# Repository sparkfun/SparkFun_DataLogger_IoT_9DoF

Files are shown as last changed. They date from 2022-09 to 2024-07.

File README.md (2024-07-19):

SparkFun DataLogger IoT – 9DoF
========================================

SparkFun DataLogger IoT – 9DoF (https://www.sparkfun.com/products/20594)

[*SparkFun DataLogger IoT – 9DoF (DEV-20594)*](https://www.sparkfun.com/products/20594)

An IoT-enabled ESP32-based logger with on-board IMU and magnetometer. The microSD interface is full 4-bit SDIO for fast logging.

Repository Contents
-------------------
* **/Firmware** - Example code for hardware testing
* **/Hardware** - Eagle design files (.brd, .sch)

Documentation
-------------------

* **[Hookup Guide](https://docs.sparkfun.com/SparkFun_DataLogger/)** - Basic hookup guide for the Datalogger IoT
* **[Firmware](https://github.com/sparkfun/SparkFun_DataLogger/)** - Repo for the Datalogger IoT

Product Versions
----------------

* [DEV-20594](https://www.sparkfun.com/products/20594) - v1.1 & v1.2 (minor silkscreen change)

Version History
---------------
- V1.2 - DataLogger IoT – 9DoF with minor silkscreen change
- V1.1 - Initial release, rename to DataLogger IoT – 9DoF

License Information
-------------------

This hardware and the hardware test sketches contained in this GitHub repo are _**open source**_!

Please review the LICENSE.md file for license information. 

If you have any questions or concerns on licensing, please contact technical support on our [SparkFun forums](https://forum.sparkfun.com/viewforum.php?f=152).

Distributed as-is; no warranty is given.

- Your friends at SparkFun.

_<COLLABORATION CREDIT>_

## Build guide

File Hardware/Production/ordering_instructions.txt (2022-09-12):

panel size, 116x155mm
PCB thickness, 1.6mm
number of layers, 4
soldermask color, Red
silkscreen color, White
oz copper, 1oz
finish, HASL lead free
stencils, top+bottom
pcs per panel, 6
min trace width, 0.1524mm / 0.0060in
min drill size, 0.3000mm / 0.0118in
filename to layer stackup 1/2/3/4: GTL, GL2, GL3, GBL

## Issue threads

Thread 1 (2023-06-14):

DATALOGGER IOT - 9DOF DOES NOT RECOGNIZE SAM-M8Q GPS BOARD

csqrd, 2023-06-14:
It appears that the datalogger does not recognize the M8Q as it does not show up as a device along with the other 3 built-in devices. I updated the datalogger to firmware version 01.00.02 which did not resolve the issue. I verified that the SAM-M8Q board is functioning properly by using the U-Blox u-center software and a SparkFun u-blox GNSS Arduino example sketch. The I2C address is 0x42. Any help would be appreciated.

 I did notice "[W] GNSS::isConnected no traffic seen (first attempt)" message but would expect the module to show up in the device list? I assumed a GPS fix was established by the 1 per second flashing "PPM" LED but will need to use a arduino sketch to confirm.

Here is the datalogger output:

ets Jul 29 2019 12:21:46

rst:0x1 (POWERON_RESET),boot:0x13 (SPI_FAST_FLASH_BOOT)
configsip: 0, SPIWP:0xee
clk_drv:0x00,q_drv:0x00,d_drv:0x00,cs0_drv:0x00,hd_drv:0x00,wp_drv:0x00
mode:DIO, clock div:1
load:0x3fff0030,len:1344
load:0x40078000,len:13924
ho 0 tail 12 room 4
load:0x40080400,len:3600
entry 0x400805f0
E (1096) sdmmc_common: sdmmc_init_ocr: send_op_cond (1) returned 0x107
E (1097) vfs_fat_sdmmc: sdmmc_card_init failed (0x107).
[E] Startup of the SD card failed.
[W] Error initializing the SD Card. Is an SD card installed on the board?

SparkFun DataLogger IoT - 9DOF (c) 2023 SparkFun Electronics
Version: 01.00.02 - build 000098

[W] GNSS::isConnected no traffic seen (first attempt)
Restoring System Settings ...restored from ESP32 Preferences
Connecting to WiFi...Connected to gnet
NTP startup [5 secs].......enabled
Loading devices ... 3 devices detected
MAX17048 - MAX17048 LiPo Battery Fuel Gauge {qwiic}
ISM330 - ISM330 Inertial Measurement Unit {SPI}
MMC5983 - MMC5983 Magnetometer {SPI}

Time: 2023-06-12T14:40:59
Uptime: 0 days, 00:00:16.246
External Time Source: NTP Client
Board Name: SparkFun DataLogger IoT - 9DoF
Board ID: SFD1D085B886E694
SD card not available
[I] WiFi - Connected SSID: gnet IP Address: 192.168.xxx.xxx Signal: Excellent
[I] Battery - Not Connected
[I] System Deep Sleep: disabled
Sleep Interval: 0 seconds
Wake Interval: 0 seconds

[I] Logging Interval (ms): 15000
[I] Serial Output: CSV Format
Baud Rate: 115200

PaulZC, 2023-06-17:
Hi @csqrd ,

Apologies for the inconvenience. I can replicate this issue.

TLDR: I think the root cause is a flaw in the DataLogger firmware driver for the u-blox GNSS. I think it is caused by the way the GNSS module is detected - by looking for messages coming from the module. This works the first time - when the module is outputting NMEA messages by default. But the driver then disables the NMEA messages, saves the port configuration, and only then enables the UBX-NAV-PVT message. When the DataLogger firmware restarts, there are no NMEA messages (because they have been disabled), and no PVT messages (because the PVT message configuration is not saved).

I will confirm this, talk to my colleagues and get this fixed in the next release.

Very best wishes,
Paul

csqrd, 2023-06-17:
Thanks for the explanation.  Excited for a fix as I have several projects planed.

PaulZC, 2023-06-20:
Hi @csqrd ,

Thank you for your patience. We have a working fix for this. A new version of the firmware will be available shortly.

Best wishes,
Paul

DragonFlameBoy, 2023-07-12:
Hello

This is my first post so apologies if this is not the correct posting approach.

I have the same issue with the **GPS-18037 MAX-M10S** its not recognised except for the fist line - just as with the SAM-M8Q so I assume its the same issue?

SparkFun DataLogger IoT - 9DOF   (c) 2023 SparkFun Electronics
Version: 01.00.02  - build 000098
[W] GNSS::isConnected no traffic seen (first attempt)
[I] Restoring System Settings ...restored from ESP32 Preferences
[I] Connecting to WiFi...Connected to Vulcan
[I] NTP startup [5 secs].......enabled
[I] Loading devices ... 3 devices detected
    MAX17048              - MAX17048 LiPo Battery Fuel Gauge  {qwiic}
    ISM330                - ISM330 Inertial Measurement Unit  {SPI}
    MMC5983               - MMC5983 Magnetometer  {SPI}

gigapod, 2023-07-12:
Hi -

This is fixed and will be in the next build/release.

If everything goes well, this should be wrapped on on Friday and published.

Thanks for your patience!

-Kirk

gigapod, 2023-07-14:
Firmware version 1.00.03 was just published and includes the fix for this issue.

The update can be applied via the menu system on the DataLogger - See update  instructions [here](https://docs.sparkfun.com/SparkFun_DataLogger/configuration/#advanced-system-update)

DragonFlameBoy, 2023-07-15:
I can confirm Firmware version 1.00.03 resolves the issue with GPS-18037 MAX-M10S.  I now get the following additional information logged on the SparkFun DataLogger IoT - 9DOF:

GNSS.Year
GNSS.Month
GNSS.Day
GNSS.Hour
GNSS.Minute
GNSS.Second
GNSS.Latitude (deg)
GNSS.Longitude (deg)
GNSS.Altitude (m)
GNSS.Altitude MSL (m)
GNSS.SIV
GNSS.Fix Type
GNSS.Carrier Solution
GNSS.Ground Speed (m/s)
GNSS.Heading (deg)
GNSS.PDOP
GNSS.Horizontal Accuracy Estima
GNSS.Vertical Accuracy Estimate
GNSS.TOW (ms)
GNSS.ISO8601
GNSS.YYYYMMDD
GNSS.YYYYDDMM
GNSS.DDMMYYYY
GNSS.HHMMSS
GNSS.Fix Type (String)
GNSS.Carrier Solution (String)

Many thanks to **csqrd** for reporting this and SparkFun for resolving this.

Chris

gigapod, 2023-07-17:
@DragonFlameBoy  - thank you for verifying the fix  is working - always helpful to get feedback.

If you have any other issues/inputs - don't hesitate to file an issue here, or on the repo we use for the firmware (https://github.com/sparkfun/SparkFun_DataLogger/tree/main).

-Kirk

csqrd, 2023-07-17:
I can verify that the M8Q works as well.
Thanks!

Closed 2023-07-14.

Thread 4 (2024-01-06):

DataLogger IoT upload format

JimKruk, 2024-01-06:
I bought this board https://www.sparkfun.com/products/20594 SparkFun DataLogger IoT with a SF TMP117 temp sensor plugged in the board. I am using the adafruit IO mqtt service. After configuring the parms for the mqtt service, wifi and the logging interval everything seems to start and connect ok:

SparkFun DataLogger IoT (c) 2023 SparkFun Electronics
Version: 01.00.04 - build 0000bb

Restoring System Settings ...restored from ESP32 Preferences
Connecting to WiFi...Connected to NETGEARMR1100
NTP startup [5 secs]...enabled
MQTT Client: connecting to MQTT endpoint io.adafruit.com:1883 ...connected
Loading devices ... 2 devices detected
TMP117 - TMP117 Precision Temperature Sensor {qwiic}
MAX17048 - MAX17048 LiPo Battery Fuel Gauge {qwiic}

Time: 2024-01-01T10:59:47
Uptime: 0 days, 00:00:09.756
External Time Source: NTP Client
Board Name: SparkFun DataLogger IoT
Board ID: SFD248966B65B7A0
[I] SD card not available
[I] WiFi - Connected SSID: NETGEARMR1100 IP Address: 192.168.1.83 Signal: Fair
[I] Battery - Not Connected
[I] System Deep Sleep: disabled
Sleep Interval: 60 seconds
Wake Interval: 120 seconds
[I] Logging Interval (ms): 60000
[I] Serial Output: Disabled
Baud Rate: 115200
[I] SD Card Output: Disabled
Rotate Period: 24 Hours

[I] IoT Services:
MQTT Client : enabled
MQTT Secure Client : disabled
HTTP IoT : disabled
AWS IoT : disabled
Azure IoT : disabled
ThingSpeak MQTT : disabled
MachineChat : disabled

[I] Connected Devices [2]:
TMP117 - TMP117 Precision Temperature Sensor {qwiic}
MAX17048 - MAX17048 LiPo Battery Fuel Gauge {qwiic}

I called the mqtt topic:
Settings for: /SparkFun DataLogger IoT/Settings/MQTT Client/MQTT Topic
Edit the value of `MQTT Topic` - data type <string>
When complete, press <Return> to accept, <ESC> to discard
MQTT Topic = zzzzzzzz/feeds/datalogger.tmp117

I disabled the outputs for the 3 fields of the max17048 device in /SparkFun DataLogger IoT/Devices Settings/MAX17048

Settings for: /SparkFun DataLogger IoT/Devices Settings/MAX17048
Outputs:
1) Voltage (V) - Battery voltage (Volts)
2) State Of Charge (%) - Battery state of charge (%)
3) Change Rate (%/hr) - Battery charge change rate (%/hr)

When I open the web console of adafruit IO I am seeing updates once a minute but in the 'value' of the tmp117 feed I see this as the value:

{"TMP117":{"Temperature (C)":27.96875},"MAX17048":{}}

I just want to see the data value for "Temperature (C)" of 27.96875 not the entire string above

Is there a config setting for that somewhere ?
thanks

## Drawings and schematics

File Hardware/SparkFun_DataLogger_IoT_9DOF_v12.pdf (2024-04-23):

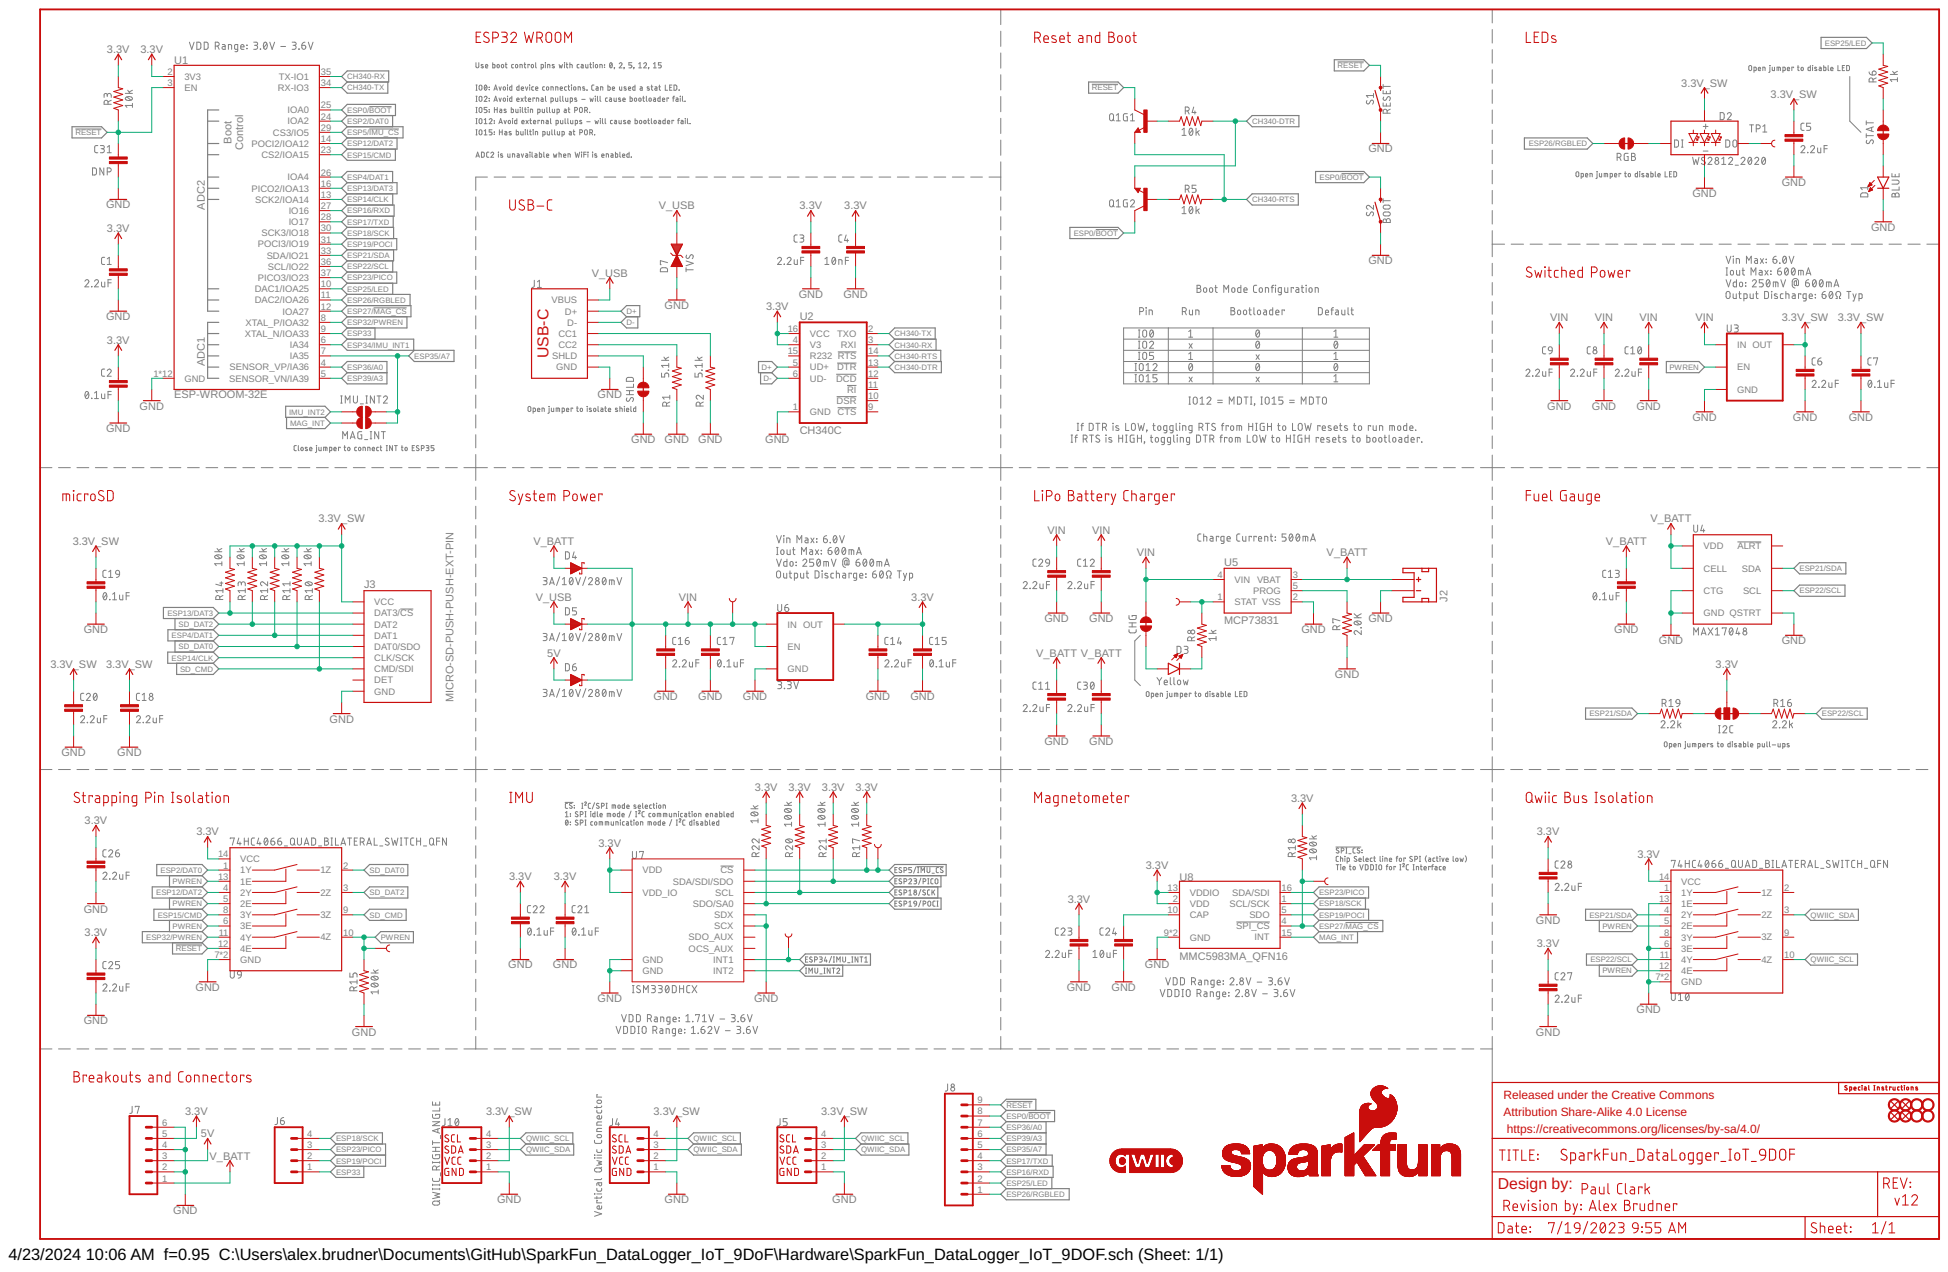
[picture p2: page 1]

GND QSTRT SCL SDA

VCC
DAT3/CS CMD/SDI DAT0/SDO
DAT2 DAT1 CLK/SCK DET

Released under the Creative Commons Attribution Share-Alike 4.0 License

https://creativecommons.org/licenses/by-sa/4.0/

4/23/2024 10:06 AM f=0.95 C:\Users\alex.brudner\Documents\GitHub\SparkFun_DataLogger_IoT_9DoF\Hardware\SparkFun_DataLogger_IoT_9DOF.sch (Sheet: 1/1)

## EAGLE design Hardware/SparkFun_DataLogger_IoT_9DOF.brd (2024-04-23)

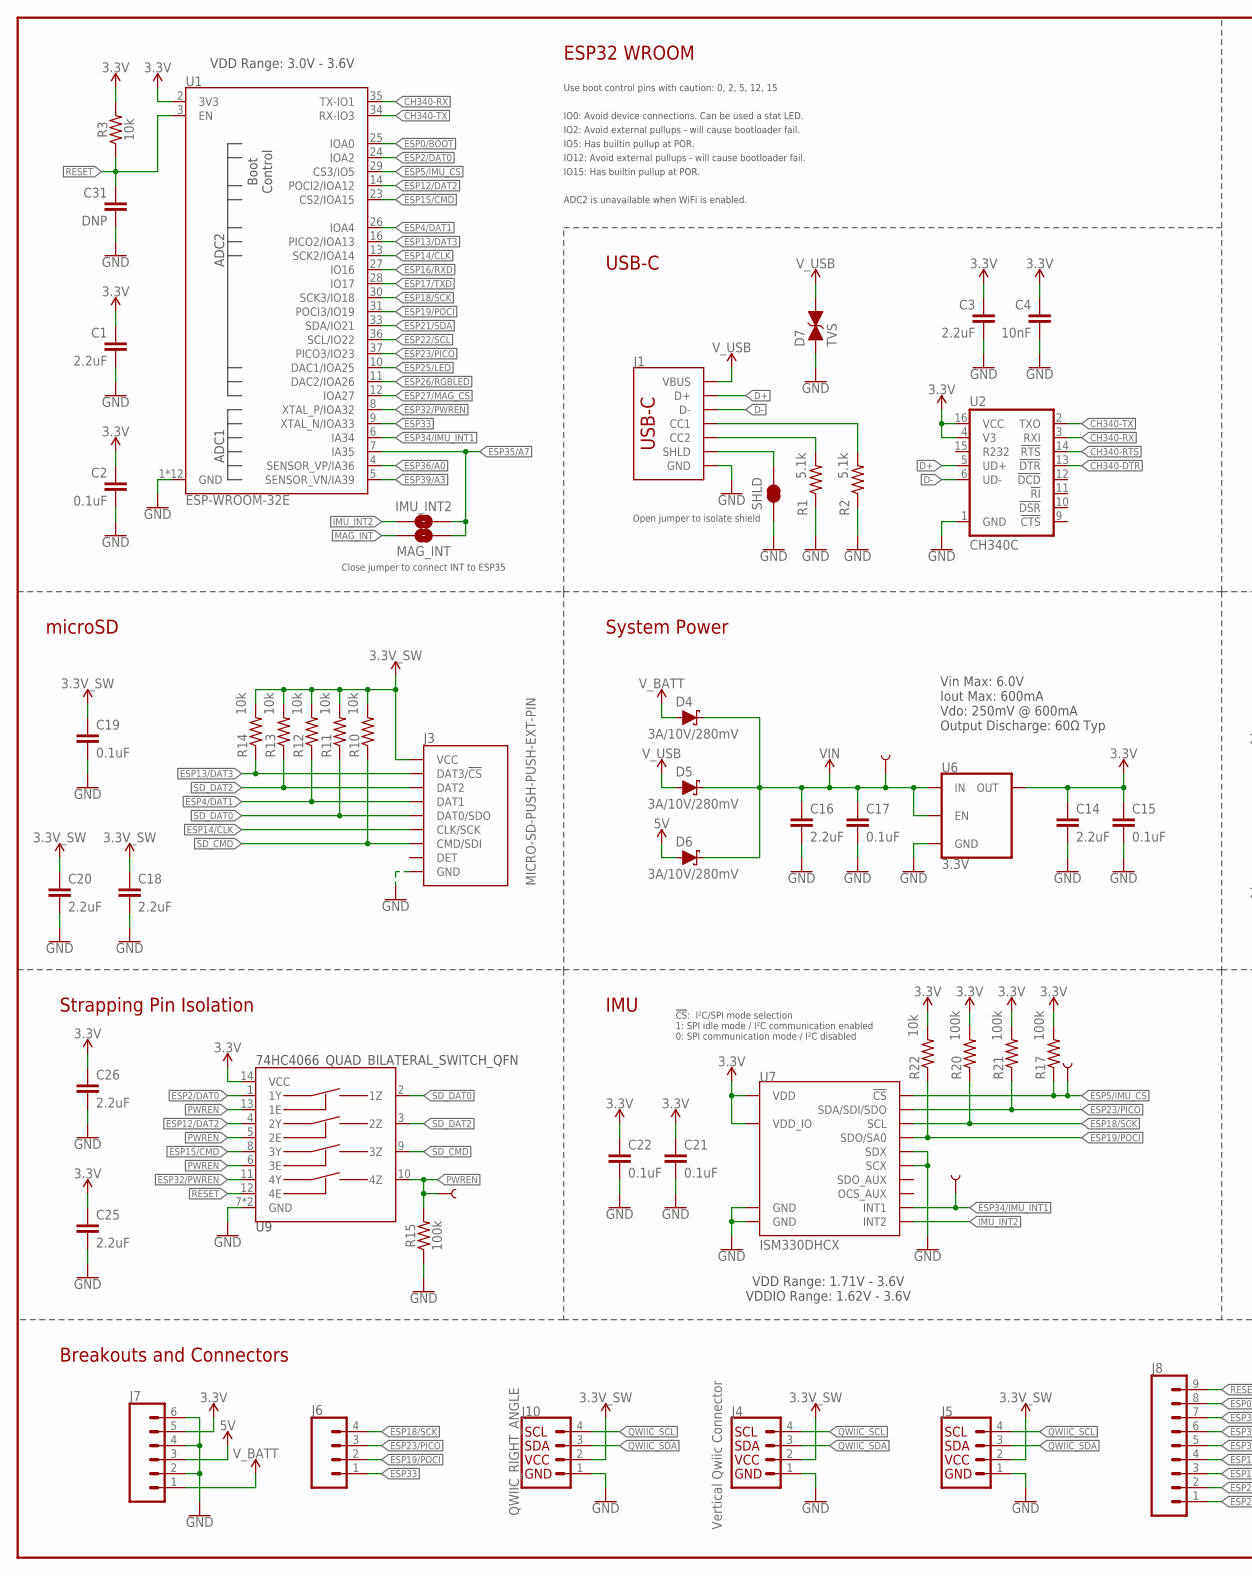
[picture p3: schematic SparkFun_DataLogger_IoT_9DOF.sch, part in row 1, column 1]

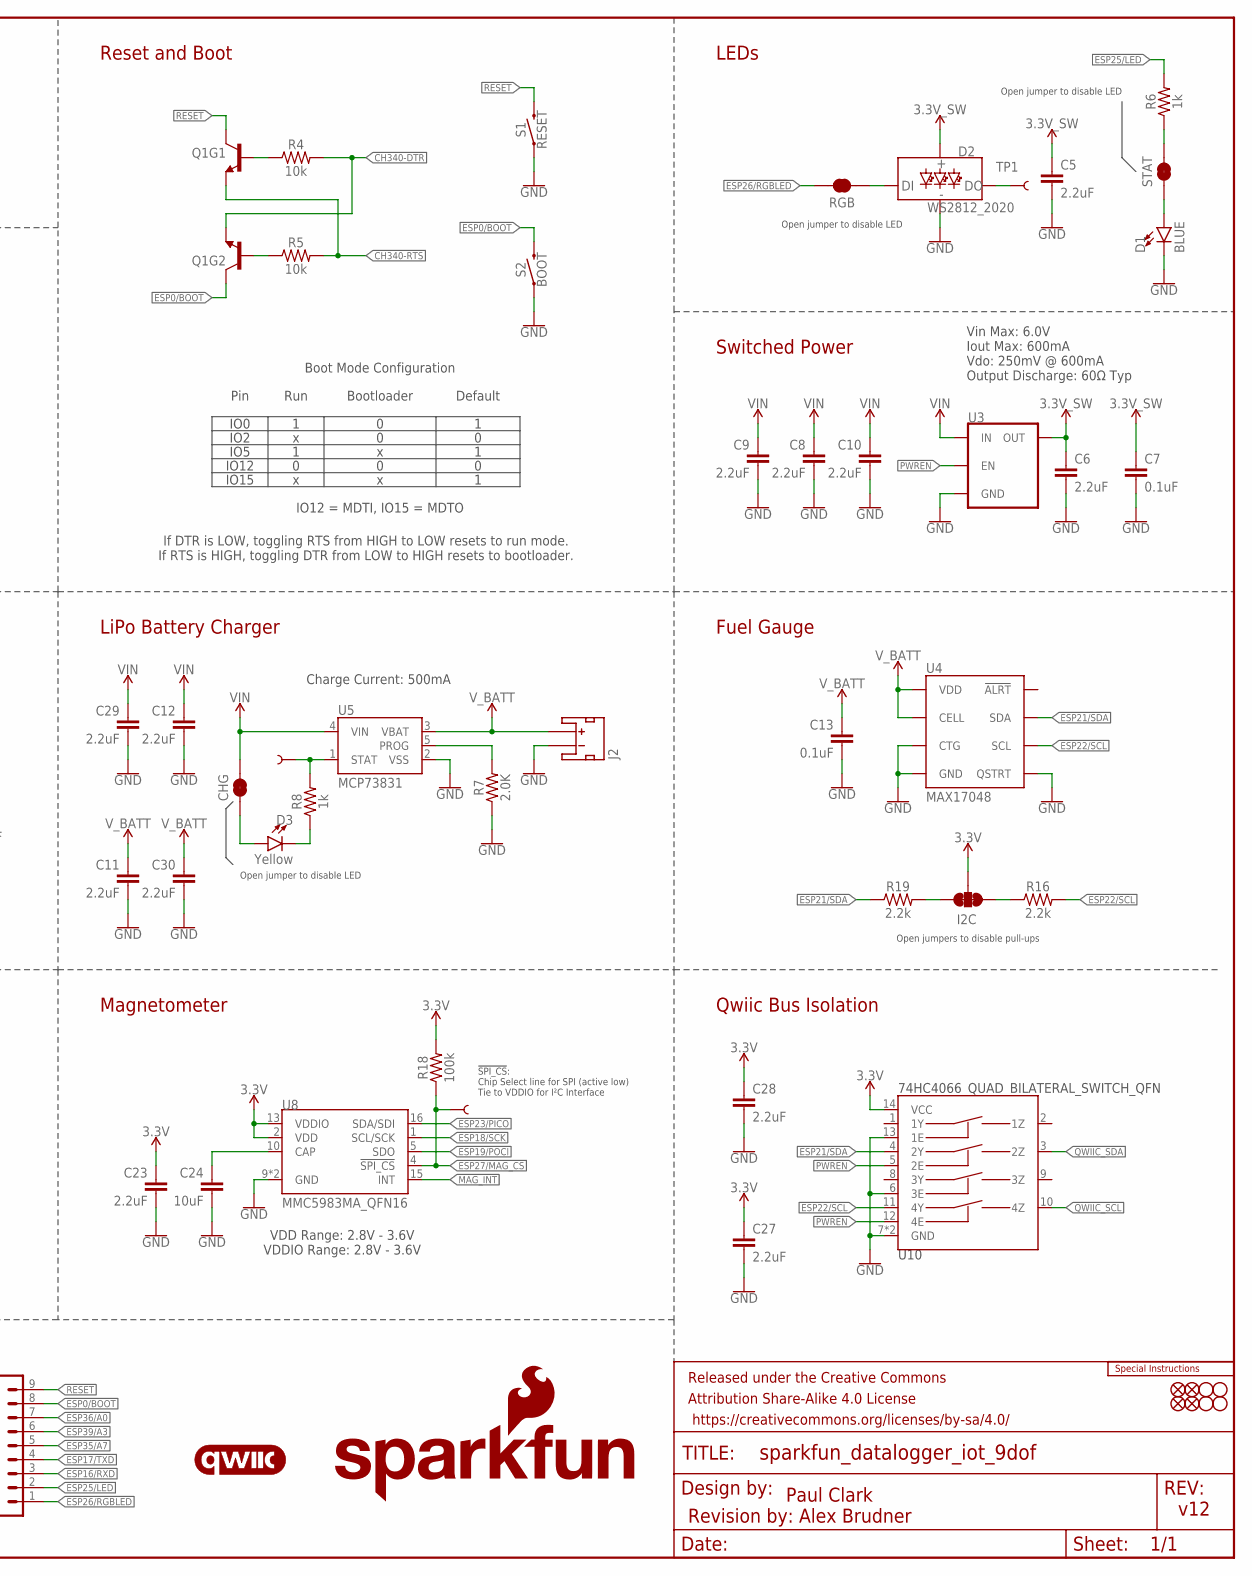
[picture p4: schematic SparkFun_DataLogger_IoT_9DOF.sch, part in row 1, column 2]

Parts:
C1, C3, C5, C6, C8, C9, C10, C11, C12, C14, C16, C18, C20, C23, C25, C26, C27, C28, C29, C30: 2.2uF; 0402-TIGHT
C2, C7, C13, C15, C17, C19, C21, C22: 0.1uF; 0402-TIGHT
C4: 10nF; 0402-TIGHT
C24: 10uF; 0402-TIGHT
C31: DNP; 0402-TIGHT_NO_CREAM
CHG: JUMPER-SMT_2_NC_TRACE_SILK; SMT-JUMPER_2_NC_TRACE_SILK
D1: BLUE; LED-0603
D2: WS2812_2020; WS2812-2020
D3: Yellow; LED-0603
D4, D5, D6: 3A/10V/280mV; SOD-323
D7: TVS; 0603
FD1, FD2, FD3, FD4: FIDUCIAL1X2; FIDUCIAL-1X2
FRAME1: FRAME-LEDGER; CREATIVE_COMMONS
H1, H2, H3, H4: STAND-OFFTIGHT; STAND-OFF-TIGHT
I2C: JUMPER-SMT_3_2-NC_TRACE_SILK; SMT-JUMPER_3_2-NC_TRACE_SILK
IMU_!CS!: TEST-POINT3X5; PAD.03X.05
IMU_INT1: TEST-POINT3X5; PAD.03X.05
IMU_INT2: JUMPER-SMT_2_NO_SILK; SMT-JUMPER_2_NO_SILK
J1: USB_C_4-LAYER_PADS; USB-C-16P_4LAYER-PADS
J2: JST_2MM_MALE; JST-2-SMD
J3: MICRO-SD-PUSH-PUSH-EXT-PIN; MICROSD-EXTERNALPIN
J4: Vertical Qwiic Connector; JST04_1MM_VERT
J5: I2C_STANDARD_NO_SILK; 1X04_NO_SILK
J6: CONN_041X04_NO_SILK_NO_POP; 1X04_NO_SILK
J7: CONN_06NO_SILK_NO_POP; 1X06_NO_SILK
J8: CONN_09NO_SILK; 1X09_NO_SILK
J10: QWIIC_RIGHT_ANGLE; JST04_1MM_RA
LOGO1: SPECIAL_INSTRUCTIONS-ORDERING; ORDERING_INSTRUCTIONS
LOGO3: QWIIC_LOGO_6MM; QWIIC_6MM
LOGO5: SFE_LOGO_NAME.2_INCH; SFE_LOGO_NAME_.2
LOGO6: SFE_LOGO_FLAME.2_INCH; SFE_LOGO_FLAME_.2
MAG_!CS!: TEST-POINT3X5; PAD.03X.05
MAG_INT: JUMPER-SMT_2_NO_SILK; SMT-JUMPER_2_NO_SILK
PWREN: TEST-POINT3X5; PAD.03X.05
Q1: TRANS_NPN_DUAL-MBT3904DW1T1; SC70-6
R1, R2: 5.1k; 0402-TIGHT
R3, R4, R5, R10, R11, R12, R13, R14, R22: 10k; 0402-TIGHT
R6, R8: 1k; 0402-TIGHT
R7: 2.0K; 0402-TIGHT
R15, R17, R18, R20, R21: 100k; 0402-TIGHT
R16, R19: 2.2k; 0402-TIGHT
RGB: JUMPER-SMT_2_NC_TRACE_SILK; SMT-JUMPER_2_NC_TRACE_SILK
S1: RESET; TACTILE_SWITCH_SMD_RIGHT_ANGLE
S2: BOOT; TACTILE_SWITCH_SMD_RIGHT_ANGLE
SHLD: JUMPER-SMT_2_NC_TRACE_SILK; SMT-JUMPER_2_NC_TRACE_SILK
STAT: JUMPER-SMT_2_NC_TRACE_SILK; SMT-JUMPER_2_NC_TRACE_SILK
TP1: TEST-POINT3X5; PAD.03X.05
U1: ESP-WROOM-32E; ESP-WROOM-32D-NARROW
U2: CH340C; SO016
U3, U6: 3.3V; SOT23-5
U4: MAX17048; DFN-8
U5: MCP73831; SOT23-5
U7: ISM330DHCX; LGA-14L
U8: MMC5983MA_QFN16; LGA-16-3X3MM-4X4PINS
U9, U10: 74HC4066_QUAD_BILATERAL_SWITCH_QFN; 14-QFN
VIN, VIN1: TEST-POINT3X5; PAD.03X.05

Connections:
3.3V: C1.1, C2.1, C3.1, C4.1, C14.1, C15.1, C21.1, C22.1, C23.1, C25.1, C26.1, C27.1, C28.1, I2C.2, J7.5, R3.2, R17.2, R18.2, R20.2, R21.2, R22.2, U1.2 (3V3), U2.4 (V3), U2.16 (VCC), U6.5 (OUT), U7.P5 (VDD_IO), U7.P8 (VDD), U8.2 (VDD), U8.13 (VDDIO), U9.14 (VCC), U10.14 (VCC)
3.3V_SW: C5.1, C6.1, C7.1, C18.1, C19.1, C20.1, D2.VCC, J3.4 (VCC), J4.2, J5.2, J10.2, R10.2, R11.2, R12.2, R13.2, R14.2, U3.5 (OUT)
5V: D6.A, J7.3
!RESET!: C31.1, J8.9, Q1.3 (C), R3.1, S1.2, U1.3 (EN), U9.12 (4E)
CAP: C24.1, U8.10 (CAP)
CH340-DTR: Q1.1 (E), R4.2, U2.13 (!DTR)
CH340-RTS: Q1.4 (E), R5.2, U2.14 (!RTS)
CH340-RX: U1.35 (TX-IO1), U2.3 (RXI)
CH340-TX: U1.34 (RX-IO3), U2.2 (TXO)
D+: J1.A6 (D+), J1.B6 (D+), U2.5 (UD+)
D-: J1.A7 (D-), J1.B7 (D-), U2.6 (UD-)
ESP0/!BOOT!: J8.8, Q1.6 (C), S2.2, U1.25 (IOA0)
ESP2/DAT0: U1.24 (IOA2), U9.1 (1Y)
ESP4/DAT1: J3.8 (DAT1), R12.1, U1.26 (IOA4)
ESP5/!IMU_CS!: IMU_!CS!.1, R17.1, U1.29 (CS3/IO5), U7.P12 (!CS!)
ESP12/DAT2: U1.14 (POCI2/IOA12), U9.4 (2Y)
ESP13/DAT3: J3.2 (DAT3/!CS!), R14.1, U1.16 (PICO2/IOA13)
ESP14/CLK: J3.5 (CLK/SCK), U1.13 (SCK2/IOA14)
ESP15/CMD: U1.23 (CS2/IOA15), U9.8 (3Y)
ESP16/RXD: J8.3, U1.27 (IO16)
ESP17/TXD: J8.4, U1.28 (IO17)
ESP18/SCK: J6.4, R20.1, U1.30 (SCK3/IO18), U7.P13 (SCL), U8.1 (SCL/SCK)
ESP19/POCI: J6.2, R22.1, U1.31 (POCI3/IO19), U7.P1 (SDO/SA0), U8.5 (SDO)
ESP21/SDA: R19.1, U1.33 (SDA/IO21), U4.8 (SDA), U10.4 (2Y)
ESP22/SCL: R16.2, U1.36 (SCL/IO22), U4.7 (SCL), U10.11 (4Y)
ESP23/PICO: J6.3, R21.1, U1.37 (PICO3/IO23), U7.P14 (SDA/SDI/SDO), U8.16 (SDA/SDI)
ESP25/LED: J8.2, R6.2, U1.10 (DAC1/IOA25)
ESP26/RGBLED: J8.1, RGB.2, U1.11 (DAC2/IOA26)
ESP27/!MAG_CS!: MAG_!CS!.1, R18.1, U1.12 (IOA27), U8.4 (!SPI_CS!)
ESP32/PWREN: U1.8 (XTAL_P/IOA32), U9.11 (4Y)
ESP33: J6.1, U1.9 (XTAL_N/IOA33)
ESP34/IMU_INT1: IMU_INT1.1, U1.6 (IA34), U7.P4 (INT1)
ESP35/A7: IMU_INT2.2, J8.5, MAG_INT.2, U1.7 (IA35)
ESP36/A0: J8.7, U1.4 (SENSOR_VP/IA36)
ESP39/A3: J8.6, U1.5 (SENSOR_VN/IA39)
GND: C1.2, C2.2, C3.2, C4.2, C5.2, C6.2, C7.2, C8.2, C9.2, C10.2, C11.2, C12.2, C13.2, C14.2, C15.2, C16.2, C17.2, C18.2, C19.2, C20.2, C21.2, C22.2, C23.2, C24.2, C25.2, C26.2, C27.2, C28.2, C29.2, C30.2, C31.2, D1.C, D2.GND, D7.1 (A), J1.GND, J1.GND2 (GND), J2.1 (-), J3.6 (GND), J3.10 (GND), J3.11 (GND), J3.12 (GND), J3.13 (GND), J4.1, J5.1, J7.2, J7.4, J7.6, J10.1, R1.1, R2.1, R7.1, R15.1, S1.1, S2.1, SHLD.1, U1.1 (GND), U1.15 (GND), U1.38 (GND), U1.GND1 (GND), U1.GNDT1 (GND), U1.GNDT2 (GND), U1.GNDT3 (GND), U1.GNDT4 (GND), U1.GNDT5 (GND), U1.GNDT6 (GND), U1.GNDT7 (GND), U1.GNDT8 (GND), U2.1 (GND), U3.2 (GND), U4.1 (CTG), U4.4 (GND), U4.6 (QSTRT), U4.9 (GND), U5.2 (VSS), U6.2 (GND), U7.P2 (SDX), U7.P3 (SCX), U7.P6 (GND), U7.P7 (GND), U8.9 (GND), U8.11 (GND), U9.7 (GND), U9.EPAD (GND), U10.6 (3E), U10.7 (GND), U10.13 (1E), U10.EPAD (GND)
IMU_INT2: IMU_INT2.1, U7.P9 (INT2)
MAG_INT: MAG_INT.1, U8.15 (INT)
unnamed: J1.B5 (CC2), R1.2
unnamed: J1.A5 (CC1), R2.2
unnamed: Q1.2 (B), R5.1
unnamed: Q1.5 (B), R4.1
unnamed: R6.1, STAT.2
unnamed: D2.DO, TP1.1
unnamed: CHG.1, D3.A
unnamed: D3.C, R8.1
unnamed: R8.2, U5.1 (STAT), VIN1.1
unnamed: R7.2, U5.5 (PROG)
unnamed: D2.DI, RGB.1
unnamed: D1.A, STAT.1
unnamed: I2C.1, R16.1
unnamed: I2C.3, R19.2
PWREN: PWREN.1, R15.2, U3.3 (EN), U9.5 (2E), U9.6 (3E), U9.10 (4Z), U9.13 (1E), U10.5 (2E), U10.12 (4E)
QWIIC_SCL: J4.4, J5.4, J10.4, U10.10 (4Z)
QWIIC_SDA: J4.3, J5.3, J10.3, U10.3 (2Z)
SD_CMD: J3.3 (CMD/SDI), R10.1, U9.9 (3Z)
SD_DAT0: J3.7 (DAT0/SDO), R11.1, U9.2 (1Z)
SD_DAT2: J3.1 (DAT2), R13.1, U9.3 (2Z)
SHIELD: J1.SHLD1 (SHLD), J1.SHLD2 (SHLD), J1.SHLD3 (SHLD), J1.SHLD4 (SHLD), SHLD.2
VIN: C8.1, C9.1, C10.1, C12.1, C16.1, C17.1, C29.1, CHG.2, D4.C, D5.C, D6.C, U3.1 (IN), U5.4 (VIN), U6.1 (IN), U6.3 (EN), VIN.1
V_BATT: C11.1, C13.1, C30.1, D4.A, J2.2 (+), J7.1, U4.2 (CELL), U4.3 (VDD), U5.3 (VBAT)
V_USB: D5.A, D7.2 (C), J1.VBUS1 (VBUS), J1.VBUS2 (VBUS)

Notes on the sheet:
ESP32 WROOM
USB-C
Paul Clark
v12
Reset and Boot
LEDs
Switched Power
Fuel Gauge
LiPo Battery Charger
System Power
microSD
Strapping Pin Isolation
IMU
VDD Range: 1.71V - 3.6V VDDIO Range: 1.62V - 3.6V
VDD Range: 2.8V - 3.6V VDDIO Range: 2.8V - 3.6V
Magnetometer
Qwiic Bus Isolation
Breakouts and Connectors
Charge Current: 500mA
VDD Range: 3.0V - 3.6V
Vin Max: 6.0V Iout Max: 600mA Vdo: 250mV @ 600mA Output Discharge: 60Ω Typ
If DTR is LOW, toggling RTS from HIGH to LOW resets to run mode. If RTS is HIGH, toggling DTR from LOW to HIGH resets to bootloader.
Pin
IO0
IO2
IO12
IO15
IO5
Run
Bootloader
Default
IO12 = MDTI, IO15 = MDTO
Boot Mode Configuration
IO0: Avoid device connections. Can be used a stat LED.
ADC2 is unavailable when WiFi is enabled.
IO12: Avoid external pullups - will cause bootloader fail.
Use boot control pins with caution: 0, 2, 5, 12, 15
IO2: Avoid external pullups - will cause bootloader fail.
IO15: Has builtin pullup at POR.
IO5: Has builtin pullup at POR.

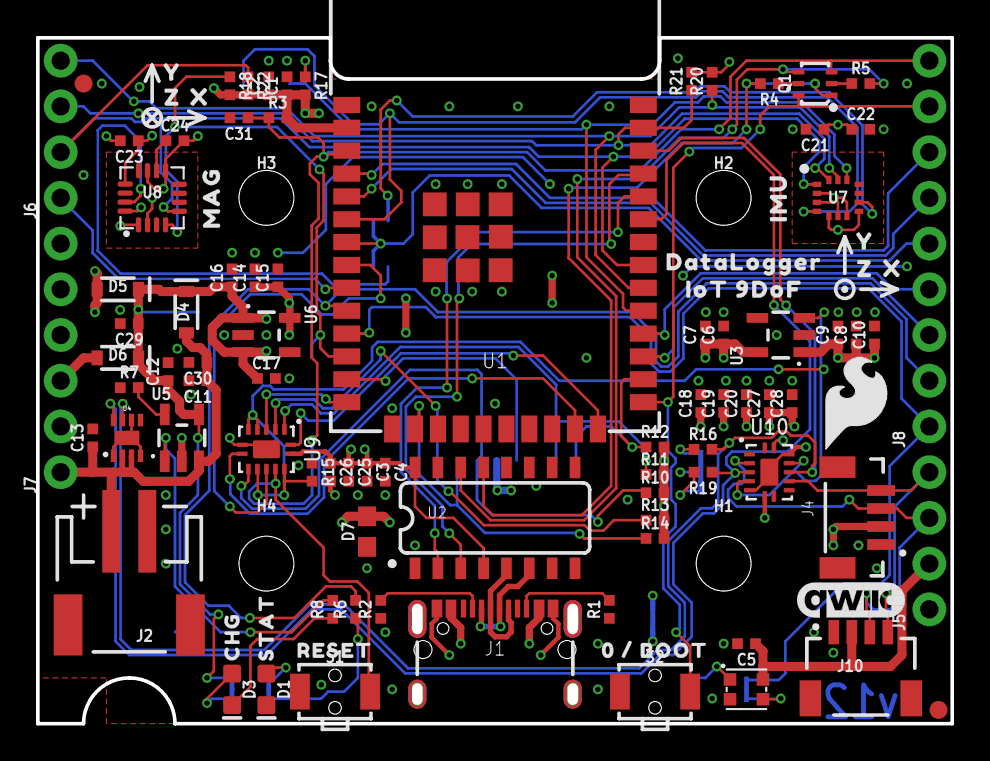
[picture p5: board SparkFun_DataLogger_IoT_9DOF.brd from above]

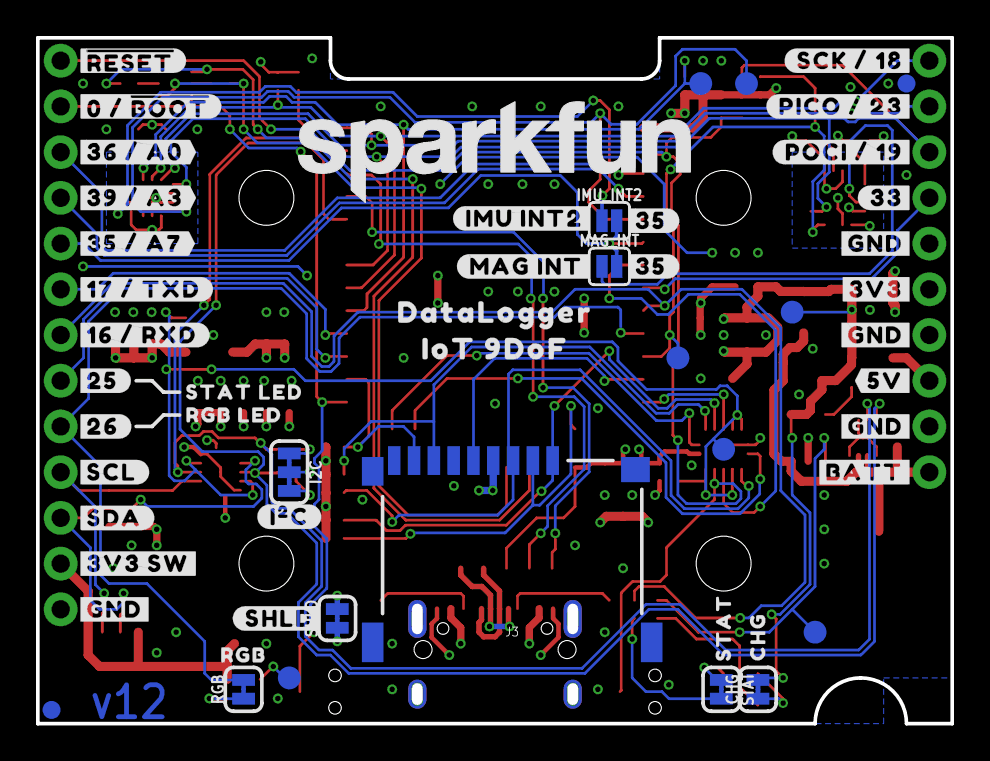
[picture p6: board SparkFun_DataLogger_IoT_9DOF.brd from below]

Board: 4 copper layers, 50.8 x 38.1 mm, 158 parts (54 on the bottom side), 62 nets.

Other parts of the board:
U$1: IOT_9DOF0
U$2: RESET0
U$3, U$6: STAT0
U$4, U$5: CHG0
U$7: 0_#_BOOT0
U$8: IMU0
U$9: MAG0
U$10, U$13: X0
U$11, U$14: Y0
U$12, U$15: Z0
U$16: ##RESET##0
U$17: #0_#_#BOOT##0
U$18: #36_#_A0#0
U$19: #39_#_A3#0
U$20: #35_#_A7#0
U$21: #17_#_TXD#0
U$22: #16_#_RXD#0
U$23: #25#0
U$24: #26#0
U$25: #SCL#0
U$26: #SDA#0
U$27: #3V3_SW#0
U$28: #GND#0
U$29, U$30, U$31: #GND#1
U$32: #BATT#0
U$33: #5V#0
U$34: #3V3#0
U$35: #33#0
U$36: #POCI_#_19#0
U$37: #PICO_#_23#0
U$38: #SCK_#_18#0
U$40: #IMU_INT2#0
U$41: #MAG_INT#0
U$42, U$43: #35#0
U$44: IOT_9DOF10
U$45: #SHLD#0
U$46: #I�C#0
U$47: STAT_LED0
U$48: RGB_LED0
U$49: RGB0
U$50: DATALOGGER0
U$51: DATALOGGER1

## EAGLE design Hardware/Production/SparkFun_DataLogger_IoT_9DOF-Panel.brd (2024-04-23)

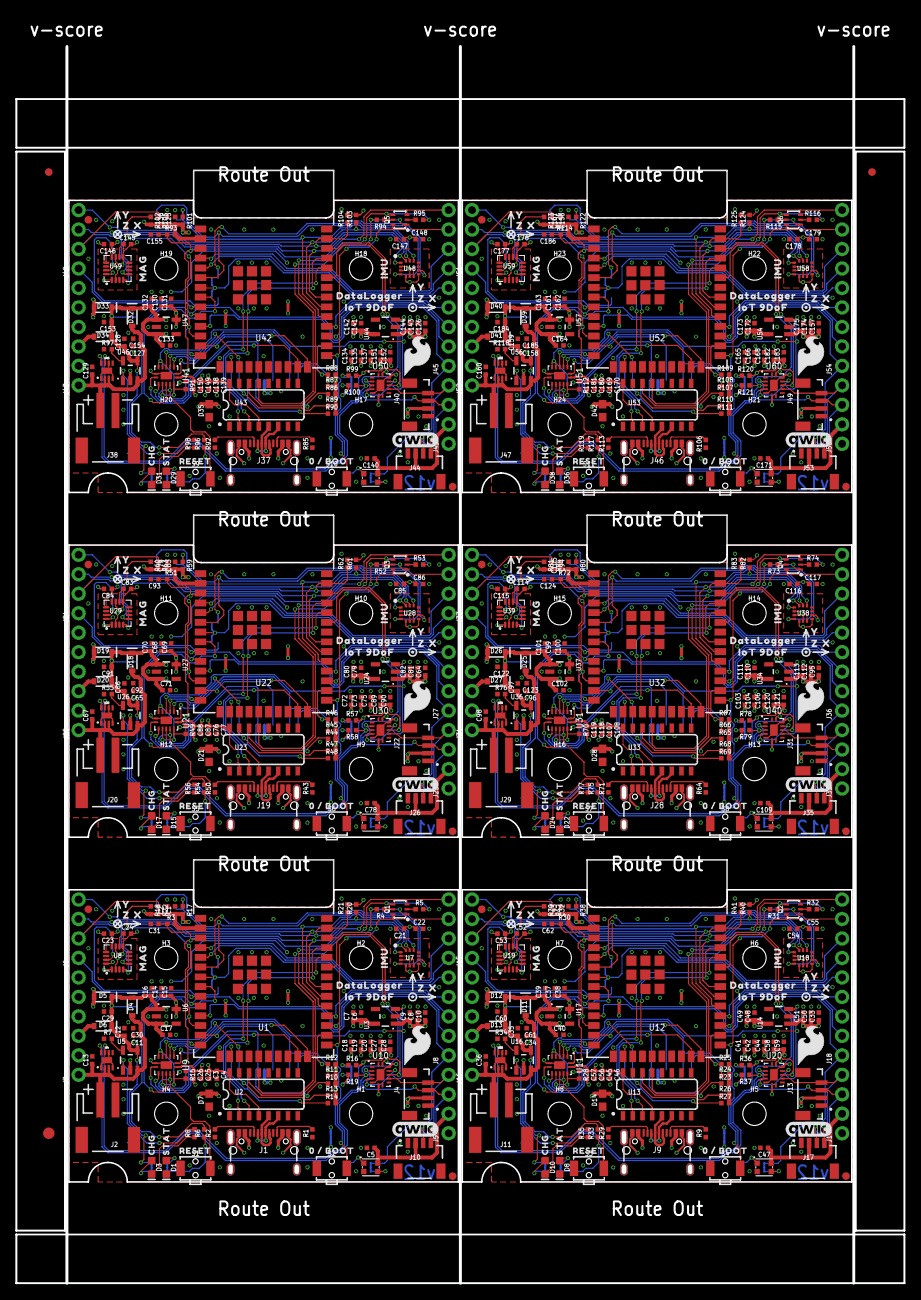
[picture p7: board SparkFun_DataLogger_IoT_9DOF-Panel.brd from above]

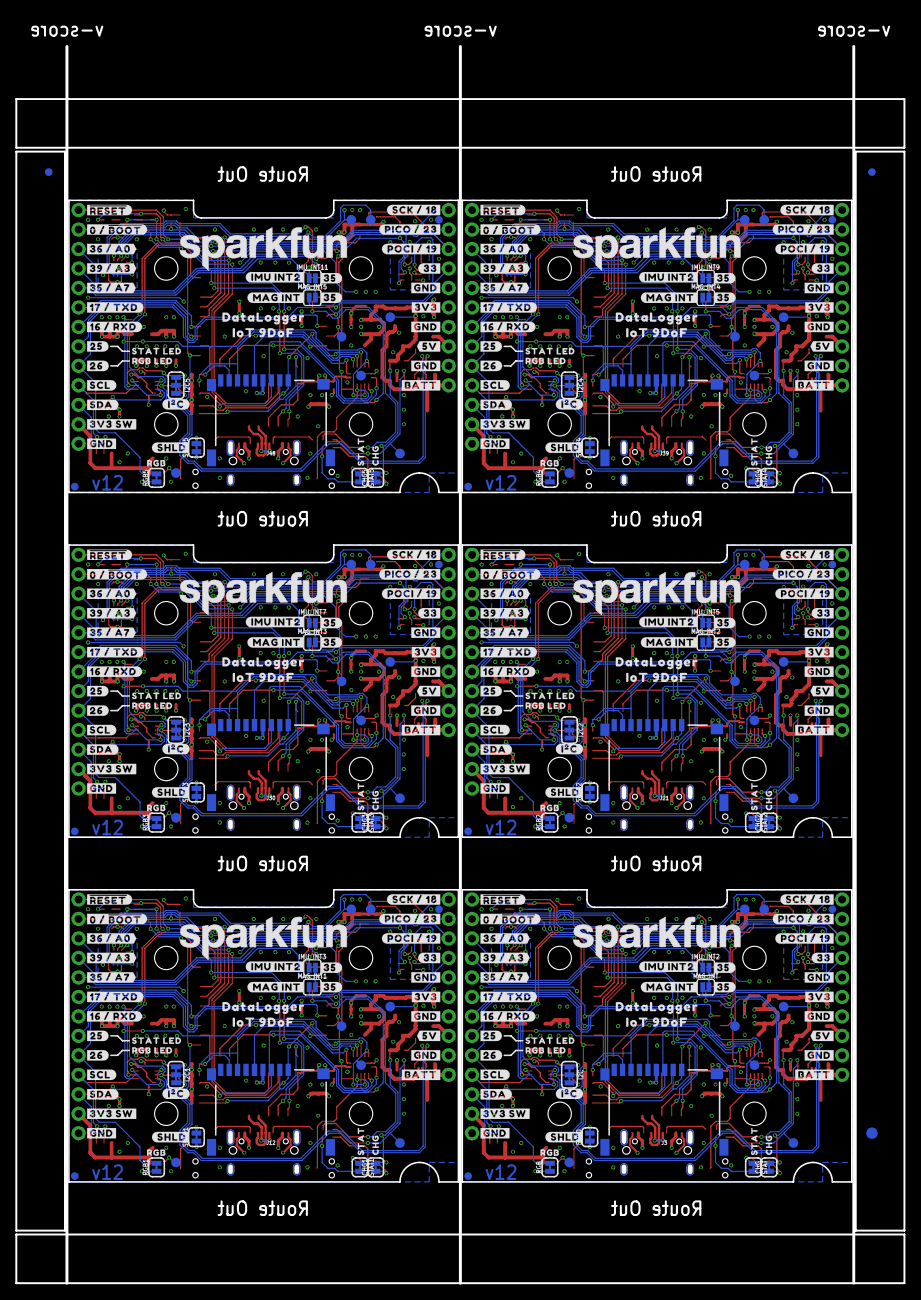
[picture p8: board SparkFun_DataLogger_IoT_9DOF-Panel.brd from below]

Board: 4 copper layers, 115.8 x 161.3 mm, 942 parts (327 on the bottom side), 372 nets.

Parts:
C1, C3, C5, C6, C8, C9, C10, C11, C12, C14, C16, C18, C20, C23, C25, C26, C27, C28, C29, C30, C32, C33, C34, C35, C37, C39, C41, C44, C45, C47, C48, C50, C51, C53, C56, C57, C58, C59, C60, C61, C63, C64, C65, C66, C68, C70, C72, C75, C76, C78, C79, C81, C82, C84, C87, C88, C89, C90, C91, C92, C94, C95, C96, C97, C99, C101, C103, C106, C107, C109, C110, C112, C113, C115, C118, C119, C120, C121, C122, C123, C125, C126, C127, C128, C130, C132, C134, C137, C138, C140, C141, C143, C144, C146, C149, C150, C151, C152, C153, C154, C156, C157, C158, C159, C161, C163, C165, C168, C169, C171, C172, C174, C175, C177, C180, C181, C182, C183, C184, C185: 2.2uF; 0402-TIGHT
C2, C7, C13, C15, C17, C19, C21, C22, C36, C38, C40, C42, C43, C49, C54, C55, C67, C69, C71, C73, C74, C80, C85, C86, C98, C100, C102, C104, C105, C111, C116, C117, C129, C131, C133, C135, C136, C142, C147, C148, C160, C162, C164, C166, C167, C173, C178, C179: 0.1uF; 0402-TIGHT
C4, C46, C77, C108, C139, C170: 10nF; 0402-TIGHT
C24, C52, C83, C114, C145, C176: 10uF; 0402-TIGHT
C31, C62, C93, C124, C155, C186: DNP; 0402-TIGHT_NO_CREAM
CHG, CHG1, CHG2, CHG3, CHG4, CHG5: JUMPER-SMT_2_NC_TRACE_SILK; SMT-JUMPER_2_NC_TRACE_SILK
D1, D8, D15, D22, D29, D36: BLUE; LED-0603
D2, D9, D16, D23, D30, D37: WS2812_2020; WS2812-2020
D3, D10, D17, D24, D31, D38: Yellow; LED-0603
D4, D5, D6, D11, D12, D13, D18, D19, D20, D25, D26, D27, D32, D33, D34, D39, D40, D41: 3A/10V/280mV; SOD-323
D7, D14, D21, D28, D35, D42: TVS; 0603
E$1, E$2, E$3, E$4: FIDUCIAL-1X2
E$5, E$6: FIDUCIAL-1.5X3
FD1, FD2, FD3, FD4, FD5, FD6, FD7, FD8, FD9, FD10, FD11, FD12, FD13, FD14, FD15, FD16, FD17, FD18, FD19, FD20, FD21, FD22, FD23, FD24: FIDUCIAL1X2; FIDUCIAL-1X2
H1, H2, H3, H4, H5, H6, H7, H8, H9, H10, H11, H12, H13, H14, H15, H16, H17, H18, H19, H20, H21, H22, H23, H24: STAND-OFFTIGHT; STAND-OFF-TIGHT
I2C, I2C1, I2C2, I2C3, I2C4, I2C5: JUMPER-SMT_3_2-NC_TRACE_SILK; SMT-JUMPER_3_2-NC_TRACE_SILK
IMU_!CS!, IMU_!CS!1, IMU_!CS!2, IMU_!CS!3, IMU_!CS!4, IMU_!CS!5: TEST-POINT3X5; PAD.03X.05
IMU_INT1, IMU_INT4, IMU_INT6, IMU_INT8, IMU_INT10, IMU_INT12: TEST-POINT3X5; PAD.03X.05
IMU_INT2, IMU_INT3, IMU_INT5, IMU_INT7, IMU_INT9, IMU_INT11: JUMPER-SMT_2_NO_SILK; SMT-JUMPER_2_NO_SILK
J1, J9, J19, J28, J37, J46: USB-C-16P_4LAYER-PADS
J2, J11, J20, J29, J38, J47: JST-2-SMD
J3, J12, J21, J30, J39, J48: MICRO-SD-PUSH-PUSH-EXT-PIN; MICROSD-EXTERNALPIN
J4, J13, J22, J31, J40, J49: Vertical Qwiic Connector; JST04_1MM_VERT
J5, J6, J14, J15, J23, J24, J32, J33, J41, J42, J50, J51: 1X04_NO_SILK
J7, J16, J25, J34, J43, J52: 1X06_NO_SILK
J8, J18, J27, J36, J45, J54: 1X09_NO_SILK
J10, J17, J26, J35, J44, J53: QWIIC_RIGHT_ANGLE; JST04_1MM_RA
LOGO1, LOGO3, LOGO7, LOGO10, LOGO13, LOGO16: QWIIC_LOGO_6MM; QWIIC_6MM
LOGO2, LOGO5, LOGO8, LOGO11, LOGO14, LOGO17: SFE_LOGO_NAME.2_INCH; SFE_LOGO_NAME_.2
LOGO4, LOGO6, LOGO9, LOGO12, LOGO15, LOGO18: SFE_LOGO_FLAME.2_INCH; SFE_LOGO_FLAME_.2
MAG_!CS!, MAG_!CS!1, MAG_!CS!2, MAG_!CS!3, MAG_!CS!4, MAG_!CS!5: TEST-POINT3X5; PAD.03X.05
MAG_INT, MAG_INT1, MAG_INT2, MAG_INT3, MAG_INT4, MAG_INT5: JUMPER-SMT_2_NO_SILK; SMT-JUMPER_2_NO_SILK
PWREN, PWREN1, PWREN2, PWREN3, PWREN4, PWREN5: TEST-POINT3X5; PAD.03X.05
Q1, Q2, Q3, Q4, Q5, Q6: SC70-6
R1, R2, R9, R29, R43, R50, R64, R71, R85, R92, R106, R113: 5.1k; 0402-TIGHT
R3, R4, R5, R10, R11, R12, R13, R14, R22, R23, R24, R25, R26, R27, R30, R31, R32, R42, R44, R45, R46, R47, R48, R51, R52, R53, R63, R65, R66, R67, R68, R69, R72, R73, R74, R84, R86, R87, R88, R89, R90, R93, R94, R95, R105, R107, R108, R109, R110, R111, R114, R115, R116, R126: 10k; 0402-TIGHT
R6, R8, R33, R35, R54, R56, R75, R77, R96, R98, R117, R119: 1k; 0402-TIGHT
R7, R34, R55, R76, R97, R118: 2.0K; 0402-TIGHT
R15, R17, R18, R20, R21, R28, R38, R39, R40, R41, R49, R59, R60, R61, R62, R70, R80, R81, R82, R83, R91, R101, R102, R103, R104, R112, R122, R123, R124, R125: 100k; 0402-TIGHT
R16, R19, R36, R37, R57, R58, R78, R79, R99, R100, R120, R121: 2.2k; 0402-TIGHT
RGB, RGB1, RGB2, RGB3, RGB4, RGB5: JUMPER-SMT_2_NC_TRACE_SILK; SMT-JUMPER_2_NC_TRACE_SILK
S1, S3, S5, S7, S9, S11: RESET; TACTILE_SWITCH_SMD_RIGHT_ANGLE
S2, S4, S6, S8, S10, S12: BOOT; TACTILE_SWITCH_SMD_RIGHT_ANGLE
SHLD, SHLD1, SHLD2, SHLD3, SHLD4, SHLD5: JUMPER-SMT_2_NC_TRACE_SILK; SMT-JUMPER_2_NC_TRACE_SILK
STAT, STAT1, STAT2, STAT3, STAT4, STAT5: JUMPER-SMT_2_NC_TRACE_SILK; SMT-JUMPER_2_NC_TRACE_SILK
TP1, TP2, TP3, TP4, TP5, TP6: TEST-POINT3X5; PAD.03X.05
U1, U12, U22, U32, U42, U52: ESP-WROOM-32E; ESP-WROOM-32D-NARROW
U2, U13, U23, U33, U43, U53: CH340C; SO016
U3, U6, U14, U17, U24, U27, U34, U37, U44, U47, U54, U57: XC6222B331MR-G; SOT23-5
U4, U15, U25, U35, U45, U55: MAX17048; DFN-8
U5, U16, U26, U36, U46, U56: MCP73831; SOT23-5
U7, U18, U28, U38, U48, U58: ISM330DHCX; LGA-14L
U8, U19, U29, U39, U49, U59: MMC5983MA_QFN16; LGA-16-3X3MM-4X4PINS
U9, U10, U11, U20, U21, U30, U31, U40, U41, U50, U51, U60: 74HC4066_QUAD_BILATERAL_SWITCH_QFN; 14-QFN
U$1, U$99, U$149, U$199, U$249, U$299: IOT_9DOF0
U$2, U$39, U$101, U$151, U$201, U$251: RESET0
U$3, U$6, U$52, U$55, U$102, U$105, U$152, U$155, U$202, U$205, U$252, U$255: STAT0
U$4, U$5, U$53, U$54, U$103, U$104, U$153, U$154, U$203, U$204, U$253, U$254: CHG0
U$7, U$95, U$145, U$195, U$245, U$295: 0_#_BOOT0
U$8, U$56, U$106, U$156, U$206, U$256: IMU0
U$9, U$57, U$107, U$157, U$207, U$257: MAG0
U$10, U$13, U$58, U$61, U$108, U$111, U$158, U$161, U$208, U$211, U$258, U$261: X0
U$11, U$14, U$59, U$62, U$109, U$112, U$159, U$162, U$209, U$212, U$259, U$262: Y0
U$12, U$15, U$60, U$63, U$110, U$113, U$160, U$163, U$210, U$213, U$260, U$263: Z0
U$16, U$64, U$114, U$164, U$214, U$264: ##RESET##0
U$17, U$65, U$115, U$165, U$215, U$265: #0_#_#BOOT##0
U$18, U$66, U$116, U$166, U$216, U$266: #36_#_A0#0
U$19, U$67, U$117, U$167, U$217, U$267: #39_#_A3#0
U$20, U$68, U$118, U$168, U$218, U$268: #35_#_A7#0
U$21, U$69, U$119, U$169, U$219, U$269: #17_#_TXD#0
U$22, U$70, U$120, U$170, U$220, U$270: #16_#_RXD#0
U$23, U$71, U$121, U$171, U$221, U$271: #25#0
U$24, U$72, U$122, U$172, U$222, U$272: #26#0
U$25, U$73, U$123, U$173, U$223, U$273: #SCL#0
U$26, U$74, U$124, U$174, U$224, U$274: #SDA#0
U$27, U$75, U$125, U$175, U$225, U$275: #3V3_SW#0
U$28, U$76, U$126, U$176, U$226, U$276: #GND#0
U$29, U$30, U$31, U$77, U$78, U$79, U$127, U$128, U$129, U$177, U$178, U$179, U$227, U$228, U$229, U$277, U$278, U$279: #GND#1
U$32, U$80, U$130, U$180, U$230, U$280: #BATT#0
U$33, U$81, U$131, U$181, U$231, U$281: #5V#0
U$34, U$82, U$132, U$182, U$232, U$282: #3V3#0
U$35, U$83, U$133, U$183, U$233, U$283: #33#0
U$36, U$84, U$134, U$184, U$234, U$284: #POCI_#_19#0
U$37, U$85, U$135, U$185, U$235, U$285: #PICO_#_23#0
U$38, U$86, U$136, U$186, U$236, U$286: #SCK_#_18#0
U$40, U$87, U$137, U$187, U$237, U$287: #IMU_INT2#0
U$41, U$88, U$138, U$188, U$238, U$288: #MAG_INT#0
U$42, U$43, U$89, U$90, U$139, U$140, U$189, U$190, U$239, U$240, U$289, U$290: #35#0
U$44, U$100, U$150, U$200, U$250, U$300: IOT_9DOF10
U$45, U$91, U$141, U$191, U$241, U$291: #SHLD#0
U$46, U$92, U$142, U$192, U$242, U$292: #I�C#0
U$47, U$93, U$143, U$193, U$243, U$293: STAT_LED0
U$48, U$94, U$144, U$194, U$244, U$294: RGB_LED0
U$49, U$96, U$146, U$196, U$246, U$296: RGB0
U$50, U$97, U$147, U$197, U$247, U$297: DATALOGGER0
U$51, U$98, U$148, U$198, U$248, U$298: DATALOGGER1
VIN, VIN1, VIN2, VIN3, VIN4, VIN5, VIN6, VIN7, VIN8, VIN9, VIN10, VIN11: TEST-POINT3X5; PAD.03X.05

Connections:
3.3V: C1.1, C2.1, C3.1, C4.1, C14.1, C15.1, C21.1, C22.1, C23.1, C25.1, C26.1, C27.1, C28.1, I2C.2, J7.5, R3.2, R17.2, R18.2, R20.2, R21.2, R22.2, U1.2, U2.4, U2.16, U6.5, U7.P5, U7.P8, U8.2, U8.13, U9.14, U10.14
3.3V1: C32.1, C37.1, C38.1, C43.1, C45.1, C46.1, C53.1, C54.1, C55.1, C56.1, C57.1, C58.1, C59.1, I2C1.2, J16.5, R30.2, R38.2, R39.2, R40.2, R41.2, R42.2, U11.14, U12.2, U13.4, U13.16, U17.5, U18.P5, U18.P8, U19.2, U19.13, U20.14
3.3V2: C63.1, C68.1, C69.1, C74.1, C76.1, C77.1, C84.1, C85.1, C86.1, C87.1, C88.1, C89.1, C90.1, I2C2.2, J25.5, R51.2, R59.2, R60.2, R61.2, R62.2, R63.2, U21.14, U22.2, U23.4, U23.16, U27.5, U28.P5, U28.P8, U29.2, U29.13, U30.14
3.3V3: C94.1, C99.1, C100.1, C105.1, C107.1, C108.1, C115.1, C116.1, C117.1, C118.1, C119.1, C120.1, C121.1, I2C3.2, J34.5, R72.2, R80.2, R81.2, R82.2, R83.2, R84.2, U31.14, U32.2, U33.4, U33.16, U37.5, U38.P5, U38.P8, U39.2, U39.13, U40.14
3.3V4: C125.1, C130.1, C131.1, C136.1, C138.1, C139.1, C146.1, C147.1, C148.1, C149.1, C150.1, C151.1, C152.1, I2C4.2, J43.5, R93.2, R101.2, R102.2, R103.2, R104.2, R105.2, U41.14, U42.2, U43.4, U43.16, U47.5, U48.P5, U48.P8, U49.2, U49.13, U50.14
3.3V5: C156.1, C161.1, C162.1, C167.1, C169.1, C170.1, C177.1, C178.1, C179.1, C180.1, C181.1, C182.1, C183.1, I2C5.2, J52.5, R114.2, R122.2, R123.2, R124.2, R125.2, R126.2, U51.14, U52.2, U53.4, U53.16, U57.5, U58.P5, U58.P8, U59.2, U59.13, U60.14
3.3V_SW: C5.1, C6.1, C7.1, C18.1, C19.1, C20.1, D2.VCC, J3.4, J4.2, J5.2, J10.2, R10.2, R11.2, R12.2, R13.2, R14.2, U3.5
3.3V_SW1: C41.1, C42.1, C44.1, C47.1, C48.1, C49.1, D9.VCC, J12.4, J13.2, J14.2, J17.2, R23.2, R24.2, R25.2, R26.2, R27.2, U14.5
3.3V_SW2: C72.1, C73.1, C75.1, C78.1, C79.1, C80.1, D16.VCC, J21.4, J22.2, J23.2, J26.2, R44.2, R45.2, R46.2, R47.2, R48.2, U24.5
3.3V_SW3: C103.1, C104.1, C106.1, C109.1, C110.1, C111.1, D23.VCC, J30.4, J31.2, J32.2, J35.2, R65.2, R66.2, R67.2, R68.2, R69.2, U34.5
3.3V_SW4: C134.1, C135.1, C137.1, C140.1, C141.1, C142.1, D30.VCC, J39.4, J40.2, J41.2, J44.2, R86.2, R87.2, R88.2, R89.2, R90.2, U44.5
3.3V_SW5: C165.1, C166.1, C168.1, C171.1, C172.1, C173.1, D37.VCC, J48.4, J49.2, J50.2, J53.2, R107.2, R108.2, R109.2, R110.2, R111.2, U54.5
5V: D6.A, J7.3
5V1: D13.A, J16.3
5V2: D20.A, J25.3
5V3: D27.A, J34.3
5V4: D34.A, J43.3
5V5: D41.A, J52.3
!RESET!: C31.1, J8.9, Q1.3, R3.1, S1.2, U1.3, U9.12
!RESET!1: C62.1, J18.9, Q2.3, R30.1, S3.2, U11.12, U12.3
!RESET!2: C93.1, J27.9, Q3.3, R51.1, S5.2, U21.12, U22.3
!RESET!3: C124.1, J36.9, Q4.3, R72.1, S7.2, U31.12, U32.3
!RESET!4: C155.1, J45.9, Q5.3, R93.1, S9.2, U41.12, U42.3
!RESET!5: C186.1, J54.9, Q6.3, R114.1, S11.2, U51.12, U52.3
CAP: C24.1, U8.10
CAP1: C52.1, U19.10
CAP2: C83.1, U29.10
CAP3: C114.1, U39.10
CAP4: C145.1, U49.10
CAP5: C176.1, U59.10
CH340-DTR: Q1.1, R4.2, U2.13
CH340-DTR1: Q2.1, R31.2, U13.13
CH340-DTR2: Q3.1, R52.2, U23.13
CH340-DTR3: Q4.1, R73.2, U33.13
CH340-DTR4: Q5.1, R94.2, U43.13
CH340-DTR5: Q6.1, R115.2, U53.13
CH340-RTS: Q1.4, R5.2, U2.14
CH340-RTS1: Q2.4, R32.2, U13.14
CH340-RTS2: Q3.4, R53.2, U23.14
CH340-RTS3: Q4.4, R74.2, U33.14
CH340-RTS4: Q5.4, R95.2, U43.14
CH340-RTS5: Q6.4, R116.2, U53.14
CH340-RX: U1.35, U2.3
CH340-RX1: U12.35, U13.3
CH340-RX2: U22.35, U23.3
CH340-RX3: U32.35, U33.3
CH340-RX4: U42.35, U43.3
CH340-RX5: U52.35, U53.3
CH340-TX: U1.34, U2.2
CH340-TX1: U12.34, U13.2
CH340-TX2: U22.34, U23.2
CH340-TX3: U32.34, U33.2
CH340-TX4: U42.34, U43.2
CH340-TX5: U52.34, U53.2
D+: J1.A6, J1.B6, U2.5
D+1: J9.A6, J9.B6, U13.5
D+2: J19.A6, J19.B6, U23.5
D+3: J28.A6, J28.B6, U33.5
D+4: J37.A6, J37.B6, U43.5
D+5: J46.A6, J46.B6, U53.5
D-: J1.A7, J1.B7, U2.6
D-1: J9.A7, J9.B7, U13.6
D-2: J19.A7, J19.B7, U23.6
D-3: J28.A7, J28.B7, U33.6
D-4: J37.A7, J37.B7, U43.6
D-5: J46.A7, J46.B7, U53.6
ESP0/!BOOT!: J8.8, Q1.6, S2.2, U1.25
ESP0/!BOOT!1: J18.8, Q2.6, S4.2, U12.25
ESP0/!BOOT!2: J27.8, Q3.6, S6.2, U22.25
ESP0/!BOOT!3: J36.8, Q4.6, S8.2, U32.25
ESP0/!BOOT!4: J45.8, Q5.6, S10.2, U42.25
ESP0/!BOOT!5: J54.8, Q6.6, S12.2, U52.25
ESP1: J15.1, U12.9
ESP2: J24.1, U22.9
ESP2/DAT0: U1.24, U9.1
ESP2/DAT1: U11.1, U12.24
ESP2/DAT2: U21.1, U22.24
ESP2/DAT3: U31.1, U32.24
ESP2/DAT4: U41.1, U42.24
ESP2/DAT5: U51.1, U52.24
ESP3: J33.1, U32.9
ESP4: J42.1, U42.9
ESP4/DAT1: J3.8, R12.1, U1.26
ESP4/DAT2: J12.8, R25.1, U12.26
ESP4/DAT3: J21.8, R46.1, U22.26
ESP4/DAT4: J30.8, R67.1, U32.26
ESP4/DAT5: J39.8, R88.1, U42.26
ESP4/DAT6: J48.8, R109.1, U52.26
ESP5: J51.1, U52.9
ESP5/!IMU_CS!: IMU_!CS!.1, R17.1, U1.29, U7.P12
ESP5/!IMU_CS!1: IMU_!CS!1.1, R38.1, U12.29, U18.P12
ESP5/!IMU_CS!2: IMU_!CS!2.1, R59.1, U22.29, U28.P12
ESP5/!IMU_CS!3: IMU_!CS!3.1, R80.1, U32.29, U38.P12
ESP5/!IMU_CS!4: IMU_!CS!4.1, R101.1, U42.29, U48.P12
ESP5/!IMU_CS!5: IMU_!CS!5.1, R122.1, U52.29, U58.P12
ESP12/DAT1: U11.4, U12.14
ESP12/DAT2: U1.14, U9.4
ESP12/DAT3: U21.4, U22.14
ESP12/DAT4: U31.4, U32.14
ESP12/DAT5: U41.4, U42.14
ESP12/DAT6: U51.4, U52.14
ESP13/DAT1: J12.2, R27.1, U12.16
ESP13/DAT2: J21.2, R48.1, U22.16
ESP13/DAT3: J3.2, R14.1, U1.16
ESP13/DAT4: J30.2, R69.1, U32.16
ESP13/DAT5: J39.2, R90.1, U42.16
ESP13/DAT6: J48.2, R111.1, U52.16
ESP14/CLK: J3.5, U1.13
ESP14/CLK1: J12.5, U12.13
ESP14/CLK2: J21.5, U22.13
ESP14/CLK3: J30.5, U32.13
ESP14/CLK4: J39.5, U42.13
ESP14/CLK5: J48.5, U52.13
ESP15/CMD: U1.23, U9.8
ESP15/CMD1: U11.8, U12.23
ESP15/CMD2: U21.8, U22.23
ESP15/CMD3: U31.8, U32.23
ESP15/CMD4: U41.8, U42.23
ESP15/CMD5: U51.8, U52.23
ESP16/RXD: J8.3, U1.27
ESP16/RXD1: J18.3, U12.27
ESP16/RXD2: J27.3, U22.27
ESP16/RXD3: J36.3, U32.27
ESP16/RXD4: J45.3, U42.27
ESP16/RXD5: J54.3, U52.27
ESP17/TXD: J8.4, U1.28
ESP17/TXD1: J18.4, U12.28
ESP17/TXD2: J27.4, U22.28
ESP17/TXD3: J36.4, U32.28
ESP17/TXD4: J45.4, U42.28
ESP17/TXD5: J54.4, U52.28
ESP18/SCK: J6.4, R20.1, U1.30, U7.P13, U8.1
ESP18/SCK1: J15.4, R40.1, U12.30, U18.P13, U19.1
ESP18/SCK2: J24.4, R61.1, U22.30, U28.P13, U29.1
ESP18/SCK3: J33.4, R82.1, U32.30, U38.P13, U39.1
ESP18/SCK4: J42.4, R103.1, U42.30, U48.P13, U49.1
ESP18/SCK5: J51.4, R124.1, U52.30, U58.P13, U59.1
ESP19/POCI: J6.2, R22.1, U1.31, U7.P1, U8.5
ESP19/POCI1: J15.2, R42.1, U12.31, U18.P1, U19.5
ESP19/POCI2: J24.2, R63.1, U22.31, U28.P1, U29.5
ESP19/POCI3: J33.2, R84.1, U32.31, U38.P1, U39.5
ESP19/POCI4: J42.2, R105.1, U42.31, U48.P1, U49.5
ESP19/POCI5: J51.2, R126.1, U52.31, U58.P1, U59.5
ESP21/SDA: R19.1, U1.33, U4.8, U10.4
ESP21/SDA1: R37.1, U12.33, U15.8, U20.4
ESP21/SDA2: R58.1, U22.33, U25.8, U30.4
ESP21/SDA3: R79.1, U32.33, U35.8, U40.4
ESP21/SDA4: R100.1, U42.33, U45.8, U50.4
ESP21/SDA5: R121.1, U52.33, U55.8, U60.4
ESP22/SCL: R16.2, U1.36, U4.7, U10.11
ESP22/SCL1: R36.2, U12.36, U15.7, U20.11
ESP22/SCL2: R57.2, U22.36, U25.7, U30.11
ESP22/SCL3: R78.2, U32.36, U35.7, U40.11
ESP22/SCL4: R99.2, U42.36, U45.7, U50.11
ESP22/SCL5: R120.2, U52.36, U55.7, U60.11
ESP23/PICO: J6.3, R21.1, U1.37, U7.P14, U8.16
ESP23/PICO1: J15.3, R41.1, U12.37, U18.P14, U19.16
ESP23/PICO2: J24.3, R62.1, U22.37, U28.P14, U29.16
ESP23/PICO3: J33.3, R83.1, U32.37, U38.P14, U39.16
ESP23/PICO4: J42.3, R104.1, U42.37, U48.P14, U49.16
ESP23/PICO5: J51.3, R125.1, U52.37, U58.P14, U59.16
ESP25/LED: J8.2, R6.2, U1.10
ESP25/LED1: J18.2, R33.2, U12.10
ESP25/LED2: J27.2, R54.2, U22.10
ESP25/LED3: J36.2, R75.2, U32.10
ESP25/LED4: J45.2, R96.2, U42.10
ESP25/LED5: J54.2, R117.2, U52.10
ESP26/RGBLED: J8.1, RGB.2, U1.11
ESP26/RGBLED1: J18.1, RGB1.2, U12.11
ESP26/RGBLED2: J27.1, RGB2.2, U22.11
ESP26/RGBLED3: J36.1, RGB3.2, U32.11
ESP26/RGBLED4: J45.1, RGB4.2, U42.11
ESP26/RGBLED5: J54.1, RGB5.2, U52.11
ESP27/!MAG_CS!: MAG_!CS!.1, R18.1, U1.12, U8.4
ESP27/!MAG_CS!1: MAG_!CS!1.1, R39.1, U12.12, U19.4
ESP27/!MAG_CS!2: MAG_!CS!2.1, R60.1, U22.12, U29.4
ESP27/!MAG_CS!3: MAG_!CS!3.1, R81.1, U32.12, U39.4
ESP27/!MAG_CS!4: MAG_!CS!4.1, R102.1, U42.12, U49.4
ESP27/!MAG_CS!5: MAG_!CS!5.1, R123.1, U52.12, U59.4
ESP32/PWREN: U1.8, U9.11
ESP32/PWREN1: U11.11, U12.8
ESP32/PWREN2: U21.11, U22.8
ESP32/PWREN3: U31.11, U32.8
ESP32/PWREN4: U41.11, U42.8
ESP32/PWREN5: U51.11, U52.8
ESP33: J6.1, U1.9
ESP34/IMU_INT1: IMU_INT1.1, U1.6, U7.P4
ESP34/IMU_INT2: IMU_INT4.1, U12.6, U18.P4
ESP34/IMU_INT3: IMU_INT6.1, U22.6, U28.P4
ESP34/IMU_INT4: IMU_INT8.1, U32.6, U38.P4
ESP34/IMU_INT5: IMU_INT10.1, U42.6, U48.P4
ESP34/IMU_INT6: IMU_INT12.1, U52.6, U58.P4
ESP35/A1: IMU_INT3.2, J18.5, MAG_INT1.2, U12.7
ESP35/A2: IMU_INT5.2, J27.5, MAG_INT2.2, U22.7
ESP35/A3: IMU_INT7.2, J36.5, MAG_INT3.2, U32.7
ESP35/A4: IMU_INT9.2, J45.5, MAG_INT4.2, U42.7
ESP35/A5: IMU_INT11.2, J54.5, MAG_INT5.2, U52.7
ESP35/A7: IMU_INT2.2, J8.5, MAG_INT.2, U1.7
ESP36/A0: J8.7, U1.4
ESP36/A1: J18.7, U12.4
ESP36/A2: J27.7, U22.4
ESP36/A3: J36.7, U32.4
ESP36/A4: J45.7, U42.4
ESP36/A5: J54.7, U52.4
ESP39/A1: J18.6, U12.5
ESP39/A2: J27.6, U22.5
ESP39/A3: J8.6, U1.5
ESP39/A4: J36.6, U32.5
ESP39/A5: J45.6, U42.5
ESP39/A6: J54.6, U52.5
GND: C1.2, C2.2, C3.2, C4.2, C5.2, C6.2, C7.2, C8.2, C9.2, C10.2, C11.2, C12.2, C13.2, C14.2, C15.2, C16.2, C17.2, C18.2, C19.2, C20.2, C21.2, C22.2, C23.2, C24.2, C25.2, C26.2, C27.2, C28.2, C29.2, C30.2, C31.2, D1.C, D2.GND, D7.1, J1.GND, J1.GND2, J2.1, J3.6, J3.10, J3.11, J3.12, J3.13, J4.1, J5.1, J7.2, J7.4, J7.6, J10.1, R1.1, R2.1, R7.1, R15.1, S1.1, S2.1, SHLD.1, U1.1, U1.15, U1.38, U1.GND1, U1.GNDT1, U1.GNDT2, U1.GNDT3, U1.GNDT4, U1.GNDT5, U1.GNDT6, U1.GNDT7, U1.GNDT8, U2.1, U3.2, U4.1, U4.4, U4.6, U4.9, U5.2, U6.2, U7.P2, U7.P3, U7.P6, U7.P7, U8.9, U8.11, U9.7, U9.EPAD, U10.6, U10.7, U10.13, U10.EPAD
GND1: C32.2, C33.2, C34.2, C35.2, C36.2, C37.2, C38.2, C39.2, C40.2, C41.2, C42.2, C43.2, C44.2, C45.2, C46.2, C47.2, C48.2, C49.2, C50.2, C51.2, C52.2, C53.2, C54.2, C55.2, C56.2, C57.2, C58.2, C59.2, C60.2, C61.2, C62.2, D8.C, D9.GND, D14.1, J9.GND, J9.GND2, J11.1, J12.6, J12.10, J12.11, J12.12, J12.13, J13.1, J14.1, J16.2, J16.4, J16.6, J17.1, R9.1, R28.1, R29.1, R34.1, S3.1, S4.1, SHLD1.1, U11.7, U11.EPAD, U12.1, U12.15, U12.38, U12.GND1, U12.GNDT1, U12.GNDT2, U12.GNDT3, U12.GNDT4, U12.GNDT5, U12.GNDT6, U12.GNDT7, U12.GNDT8, U13.1, U14.2, U15.1, U15.4, U15.6, U15.9, U16.2, U17.2, U18.P2, U18.P3, U18.P6, U18.P7, U19.9, U19.11, U20.6, U20.7, U20.13, U20.EPAD
GND2: C63.2, C64.2, C65.2, C66.2, C67.2, C68.2, C69.2, C70.2, C71.2, C72.2, C73.2, C74.2, C75.2, C76.2, C77.2, C78.2, C79.2, C80.2, C81.2, C82.2, C83.2, C84.2, C85.2, C86.2, C87.2, C88.2, C89.2, C90.2, C91.2, C92.2, C93.2, D15.C, D16.GND, D21.1, J19.GND, J19.GND2, J20.1, J21.6, J21.10, J21.11, J21.12, J21.13, J22.1, J23.1, J25.2, J25.4, J25.6, J26.1, R43.1, R49.1, R50.1, R55.1, S5.1, S6.1, SHLD2.1, U21.7, U21.EPAD, U22.1, U22.15, U22.38, U22.GND1, U22.GNDT1, U22.GNDT2, U22.GNDT3, U22.GNDT4, U22.GNDT5, U22.GNDT6, U22.GNDT7, U22.GNDT8, U23.1, U24.2, U25.1, U25.4, U25.6, U25.9, U26.2, U27.2, U28.P2, U28.P3, U28.P6, U28.P7, U29.9, U29.11, U30.6, U30.7, U30.13, U30.EPAD
GND3: C94.2, C95.2, C96.2, C97.2, C98.2, C99.2, C100.2, C101.2, C102.2, C103.2, C104.2, C105.2, C106.2, C107.2, C108.2, C109.2, C110.2, C111.2, C112.2, C113.2, C114.2, C115.2, C116.2, C117.2, C118.2, C119.2, C120.2, C121.2, C122.2, C123.2, C124.2, D22.C, D23.GND, D28.1, J28.GND, J28.GND2, J29.1, J30.6, J30.10, J30.11, J30.12, J30.13, J31.1, J32.1, J34.2, J34.4, J34.6, J35.1, R64.1, R70.1, R71.1, R76.1, S7.1, S8.1, SHLD3.1, U31.7, U31.EPAD, U32.1, U32.15, U32.38, U32.GND1, U32.GNDT1, U32.GNDT2, U32.GNDT3, U32.GNDT4, U32.GNDT5, U32.GNDT6, U32.GNDT7, U32.GNDT8, U33.1, U34.2, U35.1, U35.4, U35.6, U35.9, U36.2, U37.2, U38.P2, U38.P3, U38.P6, U38.P7, U39.9, U39.11, U40.6, U40.7, U40.13, U40.EPAD
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

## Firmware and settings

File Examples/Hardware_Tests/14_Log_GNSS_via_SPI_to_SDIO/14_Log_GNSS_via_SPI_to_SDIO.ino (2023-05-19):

// SparkFun DataLogger IoT – 9DoF Test Example
// Tested with Espressif ESP32 v2.0.5 and the "ESP32 Dev Module" board definition

/**********************************************************************************************
 *
 * WARNING!
 * 
 * This is a sketch we wrote to test the DataLogger IoT – 9DoF hardware.
 * Please think very carefully before uploading it to your DataLogger.
 * 
 * You will overwrite the DataLogger firmware, leaving it unable to update or restore itself. 
 * 
 * The DataLogger IoT – 9DoF comes pre-programmed with amazing firmware which can do _so_ much.
 * It is designed to be able to update itself and restore itself if necessary.
 * But it can not do that if you overwrite the firmware with this test sketch.
 * It is just like erasing the restore partition on your computer hard drive.
 * Do not do it - unless you really know what you are doing.
 * 
 * Really. We mean it.
 * 
 * Your friends at SparkFun.
 * 
 * License: MIT. Please see LICENSE.MD for more details
 * 
 **********************************************************************************************/

/*
  This example shows how to configure the u-blox GNSS to send RXM SFRBX and RAWX reports automatically
  and log the data to SD card in UBX format.
  
  This code is written for the DataLogger IoT – 9DoF (DEV-20594)

  Hardware set-up:
  Close the DSEL jumper on the ZED-F9P breakout - to select SPI mode
  Connect:
  DataLogger    : ZED-F9P
  GND             GND
  3V3_SW          3V3
  SCK  (18)       SCK
  PICO (23)       PICO (MOSI)
  POCI (19)       POCI (MISO)
  33              CS

  ** Please note: this example will only work on u-blox ADR or High Precision GNSS or Time Sync products **

  Data is logged in u-blox UBX format.

  Feel like supporting open source hardware?
  Buy a board from SparkFun!
  DataLogger IoT – 9DoF: https://www.sparkfun.com/products/20594
  ZED-F9P RTK2: https://www.sparkfun.com/products/15136
  NEO-M8P RTK: https://www.sparkfun.com/products/15005
*/

#define GNSS_CS 33   // Connect the ZED-F9P CS pin to DataLogger IoT – 9DoF pin 33
#define EN_3V3_SW 32 // The 3.3V_SW regulator Enable pin is connected to D32
#define STAT_LED 25  // The DataLogger IoT – 9DoF STAT LED is connected to pin 25
#define IMU_CS 5     // The ISM330 IMU CS is connected to pin 5
#define MAG_CS 27    // The MMC5983 Mag CS is connected to pin 27

#include "FS.h"
#include "SD_MMC.h"
File myFile;

#include <SPI.h>
#define spiPort SPI

#include <SparkFun_u-blox_GNSS_Arduino_Library.h> //Click here to get the library: http://librarymanager/All#SparkFun_u-blox_GNSS
SFE_UBLOX_GNSS myGNSS;

#define sdWriteSize 2048     // Write data to the SD card in blocks of n*512 bytes
#define fileBufferSize 65530 // Allocate just under 64KBytes of RAM for UBX message storage
#define navRate 20           // Set the Nav Rate (Frequency) to 20Hz
//#define ubxOnly            // Uncomment this line to log UBX (RAWX and SFRBX) only
uint8_t *myBuffer; // Use myBuffer to hold the data while we write it to SD card

unsigned long lastPrint; // Record when the last Serial print took place

// Note: we'll keep a count of how many SFRBX and RAWX messages arrive - but the count will not be completely accurate.
// If two or more SFRBX messages arrive together as a group and are processed by one call to checkUblox, the count will
// only increase by one.

int numSFRBX = 0; // Keep count of how many SFRBX message groups have been received (see note above)
int numRAWX = 0; // Keep count of how many RAWX message groups have been received (see note above)

// Callback: newSFRBX will be called when new RXM SFRBX data arrives
// See u-blox_structs.h for the full definition of UBX_RXMSFRBX_data_t
//         _____  You can use any name you like for the callback. Use the same name when you call setAutoRXMSFRBXcallback
//        /                  _____  This _must_ be UBX_RXM_SFRBX_data_t
//        |                 /               _____ You can use any name you like for the struct
//        |                 |              /
//        |                 |              |
void newSFRBX(UBX_RXM_SFRBX_data_t *ubxDataStruct)
{
  numSFRBX++; // Increment the count
}

// Callback: newRAWX will be called when new RXM RAWX data arrives
// See u-blox_structs.h for the full definition of UBX_RXMRAWX_data_t
//         _____  You can use any name you like for the callback. Use the same name when you call setAutoRXMRAWXcallback
//        /             _____  This _must_ be UBX_RXM_RAWX_data_t
//        |            /                _____ You can use any name you like for the struct
//        |            |               /
//        |            |               |
void newRAWX(UBX_RXM_RAWX_data_t *ubxDataStruct)
{
  numRAWX++; // Increment the count
}

void setup()
{
  Serial.begin(115200);

  pinMode(STAT_LED, OUTPUT); // Flash the STAT LED each time we write to the SD card
  digitalWrite(STAT_LED, LOW);

  pinMode(GNSS_CS, OUTPUT);
  digitalWrite(GNSS_CS, HIGH);
  pinMode(IMU_CS, OUTPUT);
  digitalWrite(IMU_CS, HIGH);
  pinMode(MAG_CS, OUTPUT);
  digitalWrite(MAG_CS, HIGH);

  spiPort.begin();

  // Do a fake transaction to initialize the SPI pins
  spiPort.beginTransaction(SPISettings(4000000, MSBFIRST, SPI_MODE0));
  spiPort.transfer(0);
  spiPort.endTransaction();

  pinMode(EN_3V3_SW, OUTPUT); // Enable power for the microSD card and GNSS
  digitalWrite(EN_3V3_SW, HIGH);
  
  delay(3000); // Allow time for the GNSS and SD card to start up and for Tera Term to reconnect
  Serial.println(F("SparkFun DataLogger IoT – 9DoF GNSS Logging : SPI and SDIO"));

  // -=-=-=-=-=-=-=-=-=-=-=-=-=-=-=-=-=-=-=-=-=-=-=
  // Initialize the GNSS

  Serial.println(F("Initializing the GNSS..."));

  //myGNSS.enableDebugging(); // Uncomment this line to see helpful debug messages on Serial

  myGNSS.setFileBufferSize(fileBufferSize); // setFileBufferSize must be called _before_ .begin

  // Connect to the u-blox module using SPI port, csPin and speed setting
  // ublox devices generally work up to 5MHz. We'll use 4MHz for this example:
  bool begun = false;
  do
  {
    begun = myGNSS.begin(spiPort, GNSS_CS, 4000000);
    if (!begun)
    {
      Serial.println(F("u-blox GNSS not detected on SPI bus."));
      delay(1000);
    }
  }
  while (!begun);
  
  // -=-=-=-=-=-=-=-=-=-=-=-=-=-=-=-=-=-=-=-=-=-=-=
  // Wait for a 3D fix. Get the date and time for the log file

  //myGNSS.factoryDefault(); delay(5000); // Uncomment this line to reset the module back to its factory defaults

#ifdef ubxOnly
  myGNSS.setSPIOutput(COM_TYPE_UBX); //Set the SPI port to output only UBX
#else
  myGNSS.setSPIOutput(COM_TYPE_UBX | COM_TYPE_NMEA); //Set the SPI port to output both UBX and NMEA messages
#endif

  //myGNSS.saveConfigSelective(VAL_CFG_SUBSEC_IOPORT); //Optional: save (only) the communications port settings to flash and BBR

  Serial.print(F("Waiting for a 3D fix"));

  uint8_t fix = 0;

  do
  {
    fix = myGNSS.getFixType();
    delay(1000);
    Serial.print(F("."));
  }
  while ( fix != 3 ); // Wait for a 3D fix

  Serial.println();

  uint16_t y = myGNSS.getYear();
  uint8_t M = myGNSS.getMonth();
  uint8_t d = myGNSS.getDay();
  uint8_t h = myGNSS.getHour();
  uint8_t m = myGNSS.getMinute();
  uint8_t s = myGNSS.getSecond();

  char szBuffer[40] = {'\0'};
  snprintf(szBuffer, sizeof(szBuffer), "/%04d%02d%02d%02d%02d%02d.ubx", y, M, d, h, m, s);

  Serial.println(F("GNSS initialized."));

  // -=-=-=-=-=-=-=-=-=-=-=-=-=-=-=-=-=-=-=-=-=-=-=
  // Initialize the SD card. Open the log file

  Serial.println(F("Initializing SD card..."));

  // Begin the SD card
  if(!SD_MMC.begin())
  {
    Serial.println(F("Card mount failed. Freezing..."));
    while(1);
  }

  // Open the log file for writing
  Serial.printf("Log file is: %s\r\n", szBuffer);
  myFile = SD_MMC.open((const char *)szBuffer, FILE_WRITE);
  if(!myFile)
  {
    Serial.println(F("Failed to open log file for writing. Freezing..."));
    while(1);
  }

  Serial.println(F("SD card initialized."));

  // -=-=-=-=-=-=-=-=-=-=-=-=-=-=-=-=-=-=-=-=-=-=-=
  // Wait for a key press

  while (Serial.available()) // Make sure the Serial buffer is empty
  {
    Serial.read();
  }

  Serial.println(F("Press any key to start logging."));

  while (!Serial.available()) // Wait for the user to press a key
  {
    ; // Do nothing
  }

  delay(100); // Wait, just in case multiple characters were sent

  while (Serial.available()) // Empty the Serial buffer
  {
    Serial.read();
  }

  // -=-=-=-=-=-=-=-=-=-=-=-=-=-=-=-=-=-=-=-=-=-=-=
  // Enable RAWX and SFRBX

  myGNSS.setAutoRXMSFRBXcallbackPtr(&newSFRBX); // Enable automatic RXM SFRBX messages with callback to newSFRBX

  myGNSS.logRXMSFRBX(); // Enable RXM SFRBX data logging

  myGNSS.setAutoRXMRAWXcallbackPtr(&newRAWX); // Enable automatic RXM RAWX messages with callback to newRAWX

  myGNSS.logRXMRAWX(); // Enable RXM RAWX data logging

  myBuffer = new uint8_t[sdWriteSize]; // Create our own buffer to hold the data while we write it to SD card  

#ifndef ubxOnly
  myGNSS.enableNMEAMessage(UBX_NMEA_GGA, COM_PORT_SPI, navRate); // Ensure the GxGGA (Global positioning system fix data) message is enabled. Send every second.
  myGNSS.enableNMEAMessage(UBX_NMEA_GSA, COM_PORT_SPI, navRate); // Ensure the GxGSA (GNSS DOP and Active satellites) message is enabled. Send every second.
  myGNSS.enableNMEAMessage(UBX_NMEA_GSV, COM_PORT_SPI, navRate); // Ensure the GxGSV (GNSS satellites in view) message is enabled. Send every second.
  myGNSS.enableNMEAMessage(UBX_NMEA_GST, COM_PORT_SPI, navRate); // Ensure the GxGST (Position error statistics) message is enabled. Send every second.
  myGNSS.enableNMEAMessage(UBX_NMEA_RMC, COM_PORT_SPI, navRate); // Ensure the GxRMC (Recommended minimum: position, velocity and time) message is enabled. Send every second.
  myGNSS.setNMEALoggingMask(SFE_UBLOX_FILTER_NMEA_GGA | SFE_UBLOX_FILTER_NMEA_GSA | SFE_UBLOX_FILTER_NMEA_GSV | SFE_UBLOX_FILTER_NMEA_GST | SFE_UBLOX_FILTER_NMEA_RMC); // Log only these NMEA messages
#endif

  myGNSS.setNavigationFrequency(navRate); // Set navigation rate

  Serial.println(F("Press any key to stop logging."));

  lastPrint = millis(); // Initialize lastPrint
}

void loop()
{
  // =-=-=-=-=-=-=-=-=-=-=-=-=-=-=-=-=-=-=-=-

  myGNSS.checkUblox(); // Check for the arrival of new data and process it.
  myGNSS.checkCallbacks(); // Check if any callbacks are waiting to be processed.

  // =-=-=-=-=-=-=-=-=-=-=-=-=-=-=-=-=-=-=-=-

  while (myGNSS.fileBufferAvailable() >= sdWriteSize) // Check to see if we have at least sdWriteSize waiting in the buffer
  {
    digitalWrite(STAT_LED, HIGH); // Flash the STAT LED each time we write to the SD card

    myGNSS.extractFileBufferData(myBuffer, sdWriteSize); // Extract exactly sdWriteSize bytes from the UBX file buffer and put them into myBuffer

    myFile.write(myBuffer, sdWriteSize); // Write exactly sdWriteSize bytes from myBuffer to the ubxDataFile on the SD card

    // In case the SD writing is slow or there is a lot of data to write, keep checking for the arrival of new data
    myGNSS.checkUblox(); // Check for the arrival of new data and process it.
    myGNSS.checkCallbacks(); // Check if any callbacks are waiting to be processed.

    digitalWrite(STAT_LED, LOW); // Turn the STAT LED off again
  }

  // =-=-=-=-=-=-=-=-=-=-=-=-=-=-=-=-=-=-=-=-

  if (millis() > (lastPrint + 1000)) // Print the message count once per second
  {
    uint16_t maxBufferBytes = myGNSS.getMaxFileBufferAvail(); // Get how full the file buffer has been (not how full it is now)
    float bufferHigh = 100.0 * (float)maxBufferBytes / (float)fileBufferSize;

    Serial.print(F("Message groups received: SFRBX: ")); // Print how many message groups have been received (see note above)
    Serial.print(numSFRBX);
    Serial.print(F(" RAWX: "));
    Serial.print(numRAWX);
    Serial.print(F("  \tBuffer high tide: "));
    Serial.print(bufferHigh, 1); // It is a fun thing to watch how full the buffer gets
    if (bufferHigh > 90.)
      Serial.println(F("%!!"));
    else if (bufferHigh > 80.)
      Serial.println(F("%!"));
    else
      Serial.println(F("%"));

    lastPrint = millis(); // Update lastPrint
  }

  // =-=-=-=-=-=-=-=-=-=-=-=-=-=-=-=-=-=-=-=-

  if (Serial.available()) // Check if the user wants to stop logging
  {
    uint16_t remainingBytes = myGNSS.fileBufferAvailable(); // Check if there are any bytes remaining in the file buffer

    while (remainingBytes > 0) // While there is still data in the file buffer
    {
      digitalWrite(STAT_LED, HIGH); // Flash the STAT LED while we write to the SD card

      uint16_t bytesToWrite = remainingBytes; // Write the remaining bytes to SD card sdWriteSize bytes at a time
      if (bytesToWrite > sdWriteSize)
      {
        bytesToWrite = sdWriteSize;
      }

      myGNSS.extractFileBufferData(myBuffer, bytesToWrite); // Extract bytesToWrite bytes from the UBX file buffer and put them into myBuffer

      myFile.write(myBuffer, bytesToWrite); // Write bytesToWrite bytes from myBuffer to the ubxDataFile on the SD card

      remainingBytes -= bytesToWrite; // Decrement remainingBytes
    }

    digitalWrite(STAT_LED, LOW); // Turn the STAT LED off

    myFile.close(); // Close the data file

    myGNSS.setNavigationFrequency(1); // Set navigation rate to 1Hz

    myGNSS.disableMessage(UBX_CLASS_RXM, UBX_RXM_RAWX, COM_PORT_SPI);
    myGNSS.disableMessage(UBX_CLASS_RXM, UBX_RXM_SFRBX, COM_PORT_SPI);

    myGNSS.setSPIOutput(COM_TYPE_UBX | COM_TYPE_NMEA); // Re-enable NMEA

    Serial.println(F("Logging stopped. Freezing..."));
    while(1); // Do nothing more
  }

  // =-=-=-=-=-=-=-=-=-=-=-=-=-=-=-=-=-=-=-=-
}

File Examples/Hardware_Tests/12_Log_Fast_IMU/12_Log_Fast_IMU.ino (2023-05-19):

// SparkFun DataLogger IoT – 9DoF Test Example
// Tested with Espressif ESP32 v2.0.5 and the "ESP32 Dev Module" board definition

/**********************************************************************************************
 *
 * WARNING!
 * 
 * This is a sketch we wrote to test the DataLogger IoT – 9DoF hardware.
 * Please think very carefully before uploading it to your DataLogger.
 * 
 * You will overwrite the DataLogger firmware, leaving it unable to update or restore itself. 
 * 
 * The DataLogger IoT – 9DoF comes pre-programmed with amazing firmware which can do _so_ much.
 * It is designed to be able to update itself and restore itself if necessary.
 * But it can not do that if you overwrite the firmware with this test sketch.
 * It is just like erasing the restore partition on your computer hard drive.
 * Do not do it - unless you really know what you are doing.
 * 
 * Really. We mean it.
 * 
 * Your friends at SparkFun.
 * 
 * License: MIT. Please see LICENSE.MD for more details
 * 
 **********************************************************************************************/


// Set the IMU accel and gyro to run at 1666Hz.
// Configure the IMU so it generates an interrupt on accel Data Ready.
// Each time an IMU interrupt is detected, read the Accel and Gyro data.
// When writing the data to SD card, don't do anything too 'fancy' (like using a separate
// thread for the writer). Just write the data in blocks of 512 bytes.... And see what happens!
  

#define EN_3V3_SW 32 // The 3.3V_SW regulator Enable pin is connected to D32

#include "FS.h"
#include "SD_MMC.h"
File file;



//#define IMU_CS SS // The ISM330 chip select is connected to D5
int IMU_CS = 5;
int IMU_INT1 = 34; // The IMU INT1 is connected to D34

#include <SPI.h>

#include <SparkFun_ISM330DHCX.h> //Click here to get the library: http://librarymanager/All#SparkFun_6DoF_ISM330DHCX

// SPI instance class call
SparkFun_ISM330DHCX_SPI myISM; 

// Structs for X,Y,Z data
sfe_ism_data_t accelData; 
sfe_ism_data_t gyroData;

static volatile bool IMUInt1Seen = false; // Flag to indicate if an IMU interrupt has been seen

void IMUInt1ISR() // Interrupt Service Routine
{
  IMUInt1Seen = true;
}



//#define MAG_CS 27 // The MMC5983 chip select is connected to D27
int MAG_CS = 27;



void setup()
{
  pinMode(EN_3V3_SW, OUTPUT); // Enable power for the microSD card
  digitalWrite(EN_3V3_SW, HIGH);
  pinMode(IMU_CS, OUTPUT);
  digitalWrite(IMU_CS, HIGH);
  pinMode(MAG_CS, OUTPUT);
  digitalWrite(MAG_CS, HIGH); // De-select the mag
  pinMode(IMU_INT1, INPUT);

  delay(1000); // Allow time for the SD card to start up

  SPI.begin();

  Serial.begin(115200);

  Serial.println(F("SparkFun DataLogger IoT – 9DoF Test Example"));

  // Begin the SD card
  if(!SD_MMC.begin())
  {
    Serial.println("Card mount failed. Freezing...");
    while(1);
  }

  // Delete an existing log file
  if (SD_MMC.remove("/IMU.csv"))
      Serial.println("File deleted.");

  // Open the log file for writing
  file = SD_MMC.open("/IMU.csv", FILE_WRITE);
  if(!file)
  {
    Serial.println(F("Failed to open log file for writing. Freezing..."));
    while(1);
  }


  // Begin the IMU
  if( !myISM.begin(IMU_CS) )
  {
    Serial.println(F("IMU did not begin. Freezing..."));
    while(1);
  }

  // Reset the device to default settings
  // This if helpful is you're doing multiple uploads testing different settings. 
  myISM.deviceReset();

  // Wait for it to finish reseting
  while( !myISM.getDeviceReset() )
  { 
    delay(1);
  } 

  Serial.println(F("IMU has been reset."));
  Serial.println(F("Applying settings..."));
  delay(100);
  
  myISM.setDeviceConfig();
  myISM.setBlockDataUpdate();

  // Set the output data rate and precision of the accelerometer
  //myISM.setAccelDataRate(ISM_XL_ODR_6667Hz);
  myISM.setAccelDataRate(ISM_XL_ODR_1666Hz);
  myISM.setAccelFullScale(ISM_4g); 

  // Turn on the accelerometer's filter and apply settings. 
  //myISM.setAccelFilterLP2();
  //myISM.setAccelSlopeFilter(ISM_LP_ODR_DIV_10);

  // Set the output data rate and precision of the gyroscope
  //myISM.setGyroDataRate(ISM_GY_ODR_6667Hz);
  myISM.setGyroDataRate(ISM_GY_ODR_1666Hz);
  myISM.setGyroFullScale(ISM_500dps);

  // Set the accelerometer's status i.e. the data ready to interrupt one. 
  myISM.setAccelStatustoInt1();

  // This function call will modify which "events" trigger an interrupt.
  myISM.setIntNotification(ISM_ALL_INT_PULSED);

  myISM.setDataReadyMode(1); // Set data ready mode to pulsed

  myISM.setPinMode(false); // Set the pin mode to push-pull, active high

  // Attach the interrupt
  attachInterrupt(digitalPinToInterrupt(IMU_INT1), IMUInt1ISR, RISING);

  
  Serial.println(F("Here we go! Logging for 10 seconds..."));
}

void loop()
{
  unsigned long startTime = millis(); // Record the start time
  unsigned long counter = 0; // Record the number of samples
  unsigned long lastMicros = micros(); // Record the sample/write interval

  char csvLine[2 * 512] = {0}; // Storage for the CSV data
  char *csvLinePtr = csvLine; // Pointer to the end of the data

  // Each time an IMU interrupt is detected, read the Accel and Gyro data.
  // Write the text data in blocks of 512 bytes.
  
  while (millis() < (startTime + 10000)) // Record data for 10 seconds
  {
    if (IMUInt1Seen) // Have we seen an interrupt?
    {
      IMUInt1Seen = false; // Clear the flag
      
      myISM.getAccel(&accelData);
      myISM.getGyro(&gyroData);

      unsigned long microsNow = micros();
      
      csvLinePtr += sprintf(csvLinePtr, "%lu,%lu,%.1f,%.1f,%.1f,%.1f,%.1f,%.1f\r\n",
        microsNow, microsNow - lastMicros,
        accelData.xData, accelData.yData, accelData.zData,
        gyroData.xData, gyroData.yData, gyroData.zData);

      if (csvLinePtr >= (csvLine + 512)) // Have we got enough data to write to SD card?
      {
        file.write((const uint8_t *)csvLine, 512); // Write a block of 512 bytes
        memcpy(csvLine, (const char *)(csvLine + 512), (csvLinePtr - (csvLine + 512)) + 1); // Move the remaining text - plus the NULL - to the start of csvLine
        csvLinePtr -= 512; // Update the pointer
      }

      lastMicros = microsNow;
      counter++;
    }
  }

  file.write((const uint8_t *)csvLine, csvLinePtr - csvLine); // Write any remaining data
  file.close();

  Serial.print(F("Wrote "));
  Serial.print(counter);
  Serial.println(F(" lines to IMU.csv"));

  while(1); // Do nothing more
}

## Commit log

2022-09-12 v10 PCB with examples
    [OpenLog_ESP32-Panel.GBL, OpenLog_ESP32-Panel.GBO, OpenLog_ESP32-Panel.GBP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]
2023-02-06 v11 - SparkFun_DataLogger_IoT_9DOF
    [OpenLog_ESP32-Panel.GBL, OpenLog_ESP32-Panel.GTO, SparkFun_DataLogger_IoT_9DOF-Panel.GBL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]
2024-04-23 Push silk changes.
    [SparkFun_DataLogger_IoT_9DOF-Panel.brd, SparkFun_DataLogger_IoT_9DOF.brd, SparkFun_DataLogger_IoT_9DOF.sch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]

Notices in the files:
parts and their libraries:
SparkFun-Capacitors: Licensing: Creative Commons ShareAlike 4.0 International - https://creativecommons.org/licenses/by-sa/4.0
